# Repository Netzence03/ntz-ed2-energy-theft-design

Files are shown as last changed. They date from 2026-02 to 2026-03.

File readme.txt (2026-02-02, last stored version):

Notes:
 
1. All drill sizes are the maximum size provided by the manufacture (as required to calculate the minimum pad size).
2. All dimensions in building footprints are the maximum (including any tolerance) as defined by the manufacturer with the exception of row pitch (which is always nominal).  If only the normal sizing is provided we will input that dimension in mils, rounded to the nearest mil per our standards.
3. Slots are currently identified as entities describing the size of the slot (arcs, lines, etc.) on the board outline layer.  The extremities are identified with a via at each end.  These slots will either need to be:
	a. identified and dimensioned on your fabrication document
	b. or they will need to be converted to slots (assuming the targeted tool has a slot capability) using the process defined in your cad tool for identifying a padstack as a slot.  
		i. Typically this is only capable of a width and length of the slot and a size of the mill radius that creates the slot.  
		ii. Choosing to use the native tool slots will require removing entities on the board outline and the associated pads in the footprint.

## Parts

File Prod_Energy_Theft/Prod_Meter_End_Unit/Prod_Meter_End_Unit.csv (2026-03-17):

Reference | Qty | Value | DNP | Exclude from BOM | Exclude from Board | Footprint | Datasheet | Part Number
1k3,1k4 | 2 | R |  |  |  | Resistor_SMD:R_0805_2012Metric | ~ | RC0805FR-071KL
10k3,10k4 | 2 | R |  |  |  | Resistor_SMD:R_0805_2012Metric | ~ | RC0805FR-0710KL
C1,C2,C8,C13,C35,C40 | 6 | 100nf |  |  |  | Capacitor_SMD:C_0805_2012Metric | ~ | CL21B104KBCNNNC
C3 | 1 | 100uf |  |  |  | Capacitor_SMD:C_0805_2012Metric | ~ | EEE-FK1V101P
C5,C32 | 2 | 10uf |  |  |  | Capacitor_SMD:C_0805_2012Metric | ~ | CL21A106KOQNNNE
C6 | 1 | 150pf |  |  |  | Capacitor_SMD:C_0805_2012Metric | ~ | GRM1885C1H151JA01D
C9 | 1 | 47uf |  |  |  | Capacitor_SMD:C_0805_2012Metric | ~ | GRM32ER61E476KE15
C10,C12,C16,C18,C19 | 5 | 0.1u |  |  |  | Capacitor_SMD:C_0805_2012Metric | ~ | CL21B104KBCNNNC
C11,C17 | 2 | 10u |  |  |  | Capacitor_SMD:C_0805_2012Metric | ~ | CL21A106KOQNNNE
C14,C20 | 2 | 1u |  |  |  | Capacitor_SMD:C_0805_2012Metric | ~ | CL21B105KAFNNNE
C15 | 1 | 4.7u |  |  |  | Capacitor_SMD:C_0805_2012Metric | ~ | CL21A475KOQNNNE
C26,C27,C28,C29,C30,C31,C42,C43,C44,C45,C46,C47 | 12 | 22nf |  |  |  | Capacitor_SMD:C_0805_2012Metric | ~ | CL21B223KBCNNNC
C33,C34,C39 | 3 | 4.7uf |  |  |  | Capacitor_SMD:C_0805_2012Metric | ~ | CL21A475KOQNNNE
C36,C37 | 2 | 220nf |  |  |  | Capacitor_SMD:C_0805_2012Metric | ~ | CL21B224KBCNNNC
C38,C41 | 2 | 20pf |  |  |  | Capacitor_SMD:C_0805_2012Metric | ~ | GRM1885C1H200JA01D
D5,D6,D9,D10 | 4 | SS34 |  |  |  | Diode_SMD:D_SMA | https://www.vishay.com/docs/88751/ss32.pdf | SS34
D7 | 1 | Green |  |  |  | theftdetection:LEDC2012X120N | https://mm.digikey.com/Volume0/opasdata/d220001/medias/docus/895/LTST-C170GKT.pdf | LTST-C170GKT
D8 | 1 | Red |  |  |  | theftdetection:LEDC2012X120N | https://componentsearchengine.com/Datasheets/1/LTST-C170KRKT.pdf | LTST-C170GKT
D11,D12 | 2 | D |  |  |  | Diode_SMD:D_SOD-123 | ~ | B5819W
F1 | 1 | 0ZCH0110AF2E |  |  |  | Footprints.kicad_mod:FUSC3226X100N | https://www.belfuse.com/resources/datasheets/circuitprotection/ds-cp-0zch-series.pdf | 0ZCH0110AF2E
F3 | 1 | Polyfuse |  |  |  | Fuse:Fuse_1206_3216Metric | ~ | MF-R110
IC1 | 1 | MP1584EN-LF-Z |  |  |  | theftdetection:SOIC127P600X170-9N |  | MP1584EN-LF-Z
J1,J2,J3,J4,J10,J11,J12,J13 | 8 | Screw_Terminal_01x02 |  |  |  | TerminalBlock_Phoenix:TerminalBlock_Phoenix_MKDS-1,5-2-5.08_1x02_P5.08mm_Horizontal | ~ | MKDS-1,5-2-5.08
J6 | 1 | Jack-DC |  |  |  | Connector_BarrelJack:BarrelJack_GCT_DCJ200-10-A_Horizontal | ~ | PJ-102A
J7 | 1 | SS-52400-002 |  |  |  | theftdetection:BELFUSE_SS-52400-002 |  | SS-52400-002
J8 | 1 | U.FL-R-SMT_01_ |  |  |  | theftdetection:HRS_U.FL-R-SMT_01_ |  | U.FL-R-SMT-1
K1 | 1 | HFD2/012-S-L2-D |  |  |  | theftdetection:RELAY10_HFD2&slash_012_HNG | HFD2/012-S-L2-D | HFD2/012-S-L2-D
L1 | 1 | 15uH |  |  |  | Inductor_SMD:L_0805_2012Metric | ~ | SRN6045TA-150M
Q1,Q2 | 2 | BC817 |  |  |  | Package_TO_SOT_SMD:SOT-23 | https://www.onsemi.com/pub/Collateral/BC818-D.pdf | BC817
Q5,Q6 | 2 | AO3400A |  |  |  | Package_TO_SOT_SMD:SOT-23 | http://www.aosmd.com/pdfs/datasheet/AO3400A.pdf | AO3400A
R1,R15,R16 | 3 | 100k |  |  |  | Resistor_SMD:R_0805_2012Metric | ~ | RC0805FR-07100KL
R2 | 1 | 24k9 |  |  |  | Resistor_SMD:R_0805_2012Metric | ~ | RC0805FR-0724K9L
R9,R12 | 2 | 4K7 |  |  |  | Resistor_SMD:R_0805_2012Metric | ~ | RC0805FR-074K7L
R10,R11,R23,R24,R25,R26,R42,R43,R45,R46,R48,R49 | 12 | 1K |  |  |  | Resistor_SMD:R_0805_2012Metric | ~ | RC0805FR-071KL
R13,R14 | 2 | 5K1 |  |  |  | Resistor_SMD:R_0805_2012Metric | ~ | RC0805FR-0751KL
R17 | 1 | 210k |  |  |  | Resistor_SMD:R_0805_2012Metric | ~ | RC0805FR-07210KL
R20,R21,R22,R41,R44,R47 | 6 | 10 |  |  |  | Resistor_SMD:R_0805_2012Metric | ~ | RC0805FR-0710RL
R27,R28,R38,R39,R40 | 5 | 10k |  |  |  | Resistor_SMD:R_0805_2012Metric | ~ | RC0805FR-0710KL
R29 | 1 | 40k2 |  |  |  | Resistor_SMD:R_0805_2012Metric | ~ | RC0805FR-0740KL
R30 | 1 | 20k |  |  |  | Resistor_SMD:R_0805_2012Metric | ~ | RC0805FR-0720KL
R31,R32,R33 | 3 | 10K |  |  |  | Resistor_SMD:R_0805_2012Metric | ~ | RC0805FR-0710KL
R34 | 1 | 39k |  |  |  | Resistor_SMD:R_0805_2012Metric | ~ | RC0805FR-0739KL
R35 | 1 | IK |  |  |  | Resistor_SMD:R_0805_2012Metric | ~ | RC0805FR-071KL
R36,R37 | 2 | 330 |  |  |  | Resistor_SMD:R_0805_2012Metric | ~ | RC0805FR-07330RL
S1 | 1 | BOOT |  |  |  | theftdetection:SW_USLPT2819DT2TR |  | USLPT2819DT2TR
S2 | 1 | RESET |  |  |  | theftdetection:SW_USLPT2819DT2TR |  | USLPT2819DT2TR
U1 | 1 | TPS7A2033PDBVR |  |  |  | theftdetection:SOT95P280X145-5N |  | TPS7A2033PDBVR
U2 | 1 | ESP32-C6-MINI-1 |  |  |  | RF_Module:ESP32-C6-MINI-1 | https://www.espressif.com/sites/default/files/documentation/esp32-c6-mini-1_mini-1u_datasheet_en.pdf | ESP32-C6-MINI-1
U4 | 1 | CP2102N-Axx-xQFN20 |  |  |  | theftdetection:IC_CP2102N-A01-GQFN20 | https://www.silabs.com/documents/public/data-sheets/cp2102n-datasheet.pdf | CP2102N-A02-GQFN20
U5 | 1 | ADE7816ACPZ |  |  |  | adefootprint:QFN50P600X600X80-41N |  | ADE7816ACPZ
U6 | 1 | USBLC6-2SC6 |  |  |  | Package_TO_SOT_SMD:SOT-23-6 | https://www.st.com/resource/en/datasheet/usblc6-2.pdf | USBLC6-2SC6
U7 | 1 | AP2112K-3.3 |  |  |  | Package_TO_SOT_SMD:SOT-23-5 | https://www.diodes.com/assets/Datasheets/AP2112.pdf | AP2112K-3.3
U8 | 1 | E32-433T20S |  |  |  | theftdetection:MODULE_E32-433T20S |  | E32-433T20S
Y2 | 1 | Crystal |  |  |  | Crystal:Crystal_SMD_3225-4Pin_3.2x2.5mm | ~ | TSX-3225

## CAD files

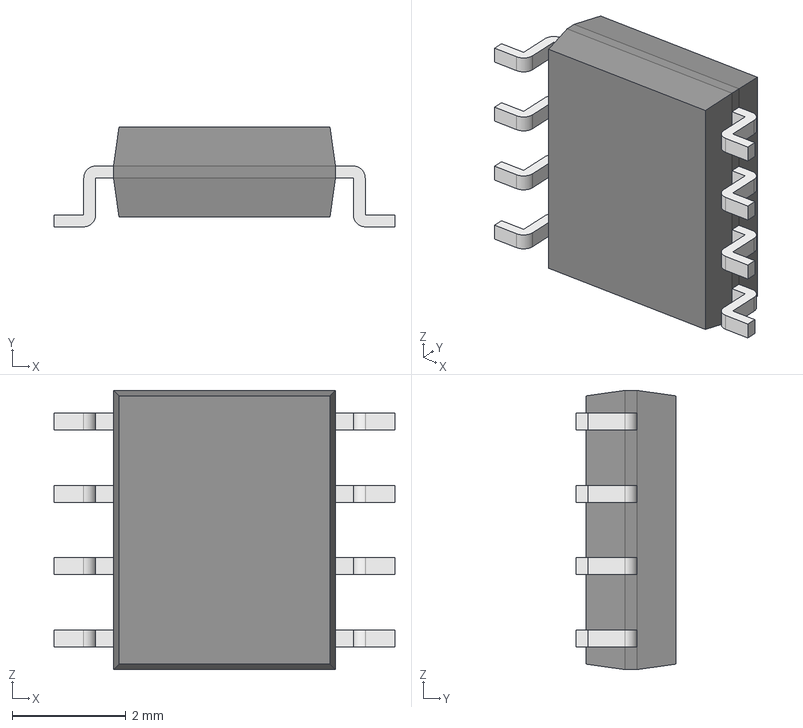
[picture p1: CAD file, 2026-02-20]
Prod_Energy_Theft/Prod_Pole_End_Unit/TPS54331DG4/TPS54331DG4.step
5.99 x 1.75 x 4.91 mm
Body001 (Mirror #1) x 4
XY-plane x 12
X-axis x 12

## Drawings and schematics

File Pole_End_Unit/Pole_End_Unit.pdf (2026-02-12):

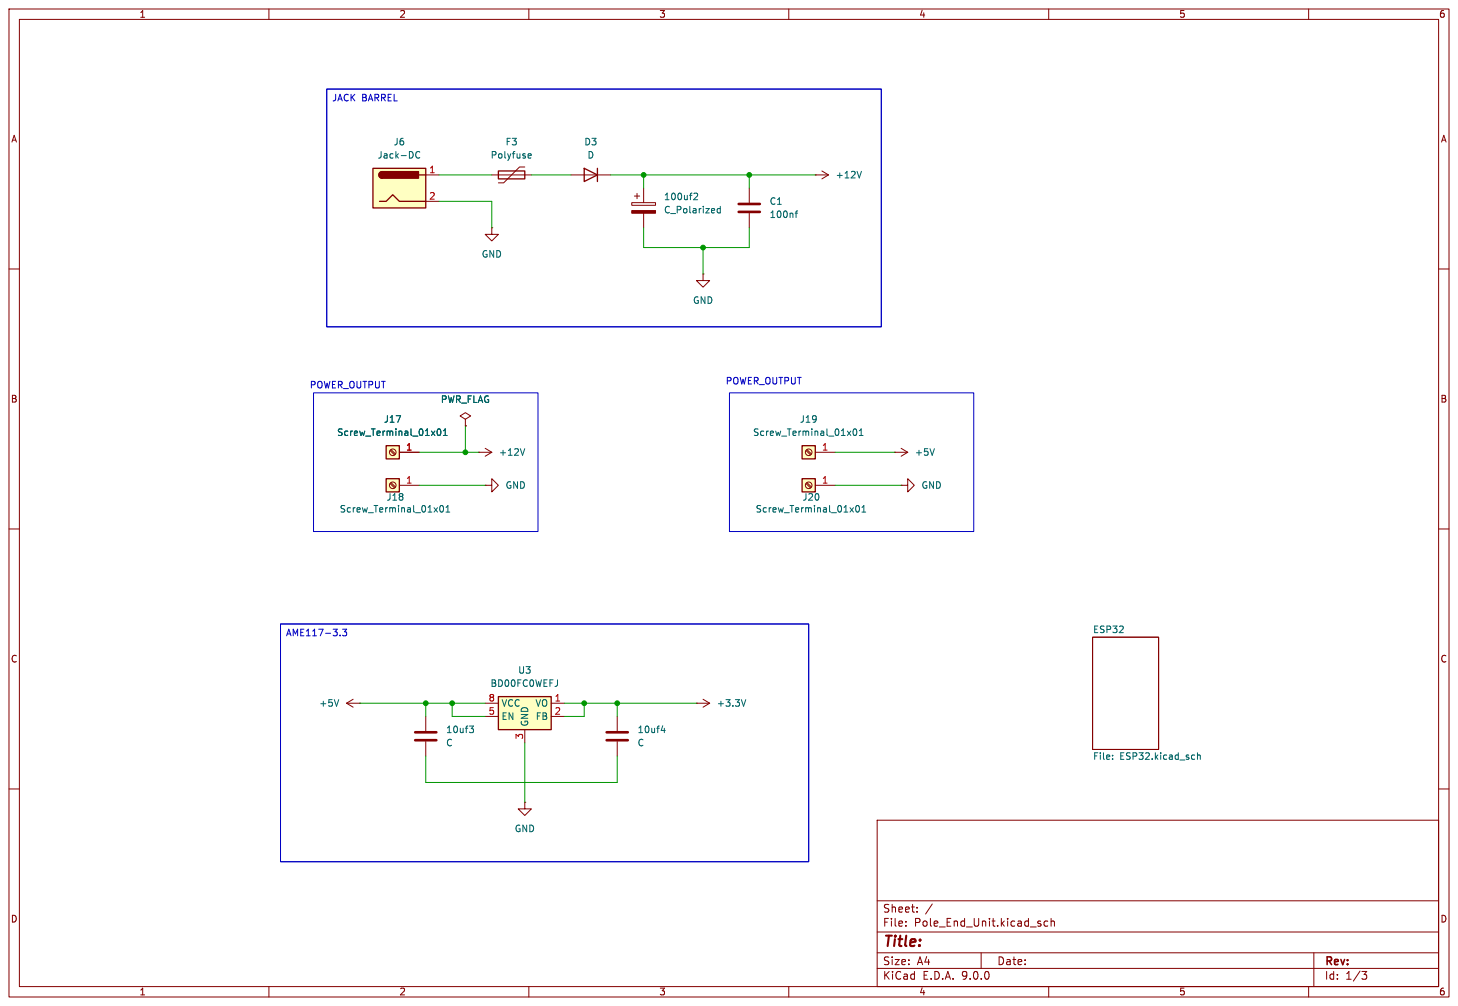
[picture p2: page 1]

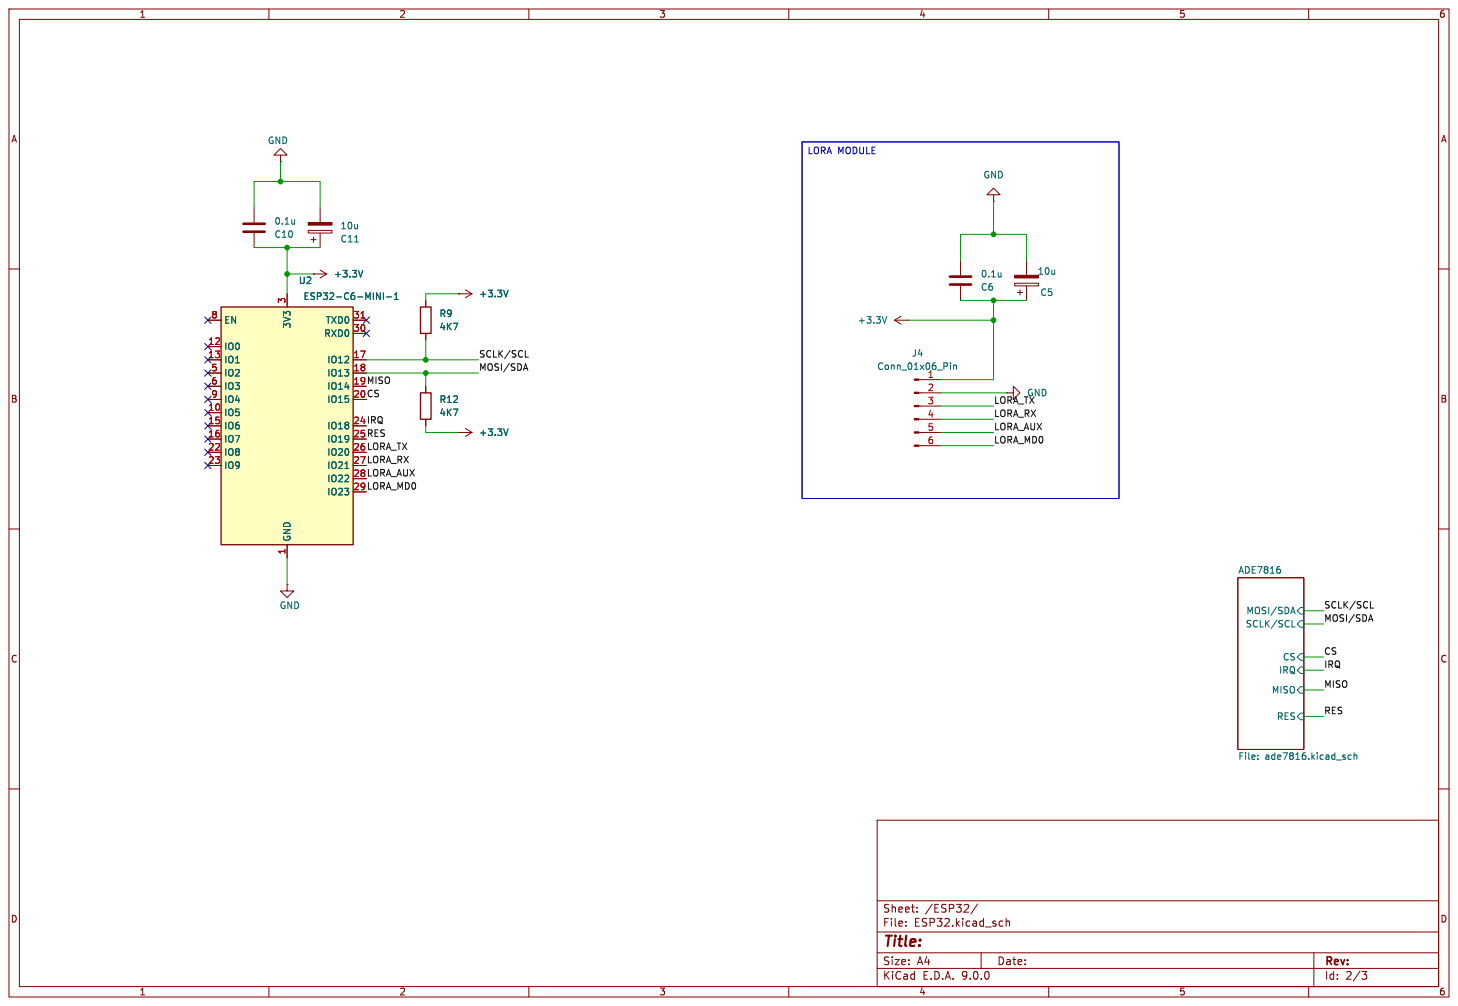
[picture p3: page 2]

LORA MODULE U2ESP32-C6-MINI-1 EN 8

SCLK/SCL MOSI/SDA

SCLK/SCL ADE7816 File: ade7816.kicad_sch GND

Id: 2/3 Title: File: ESP32.kicad_sch Sheet: /ESP32/

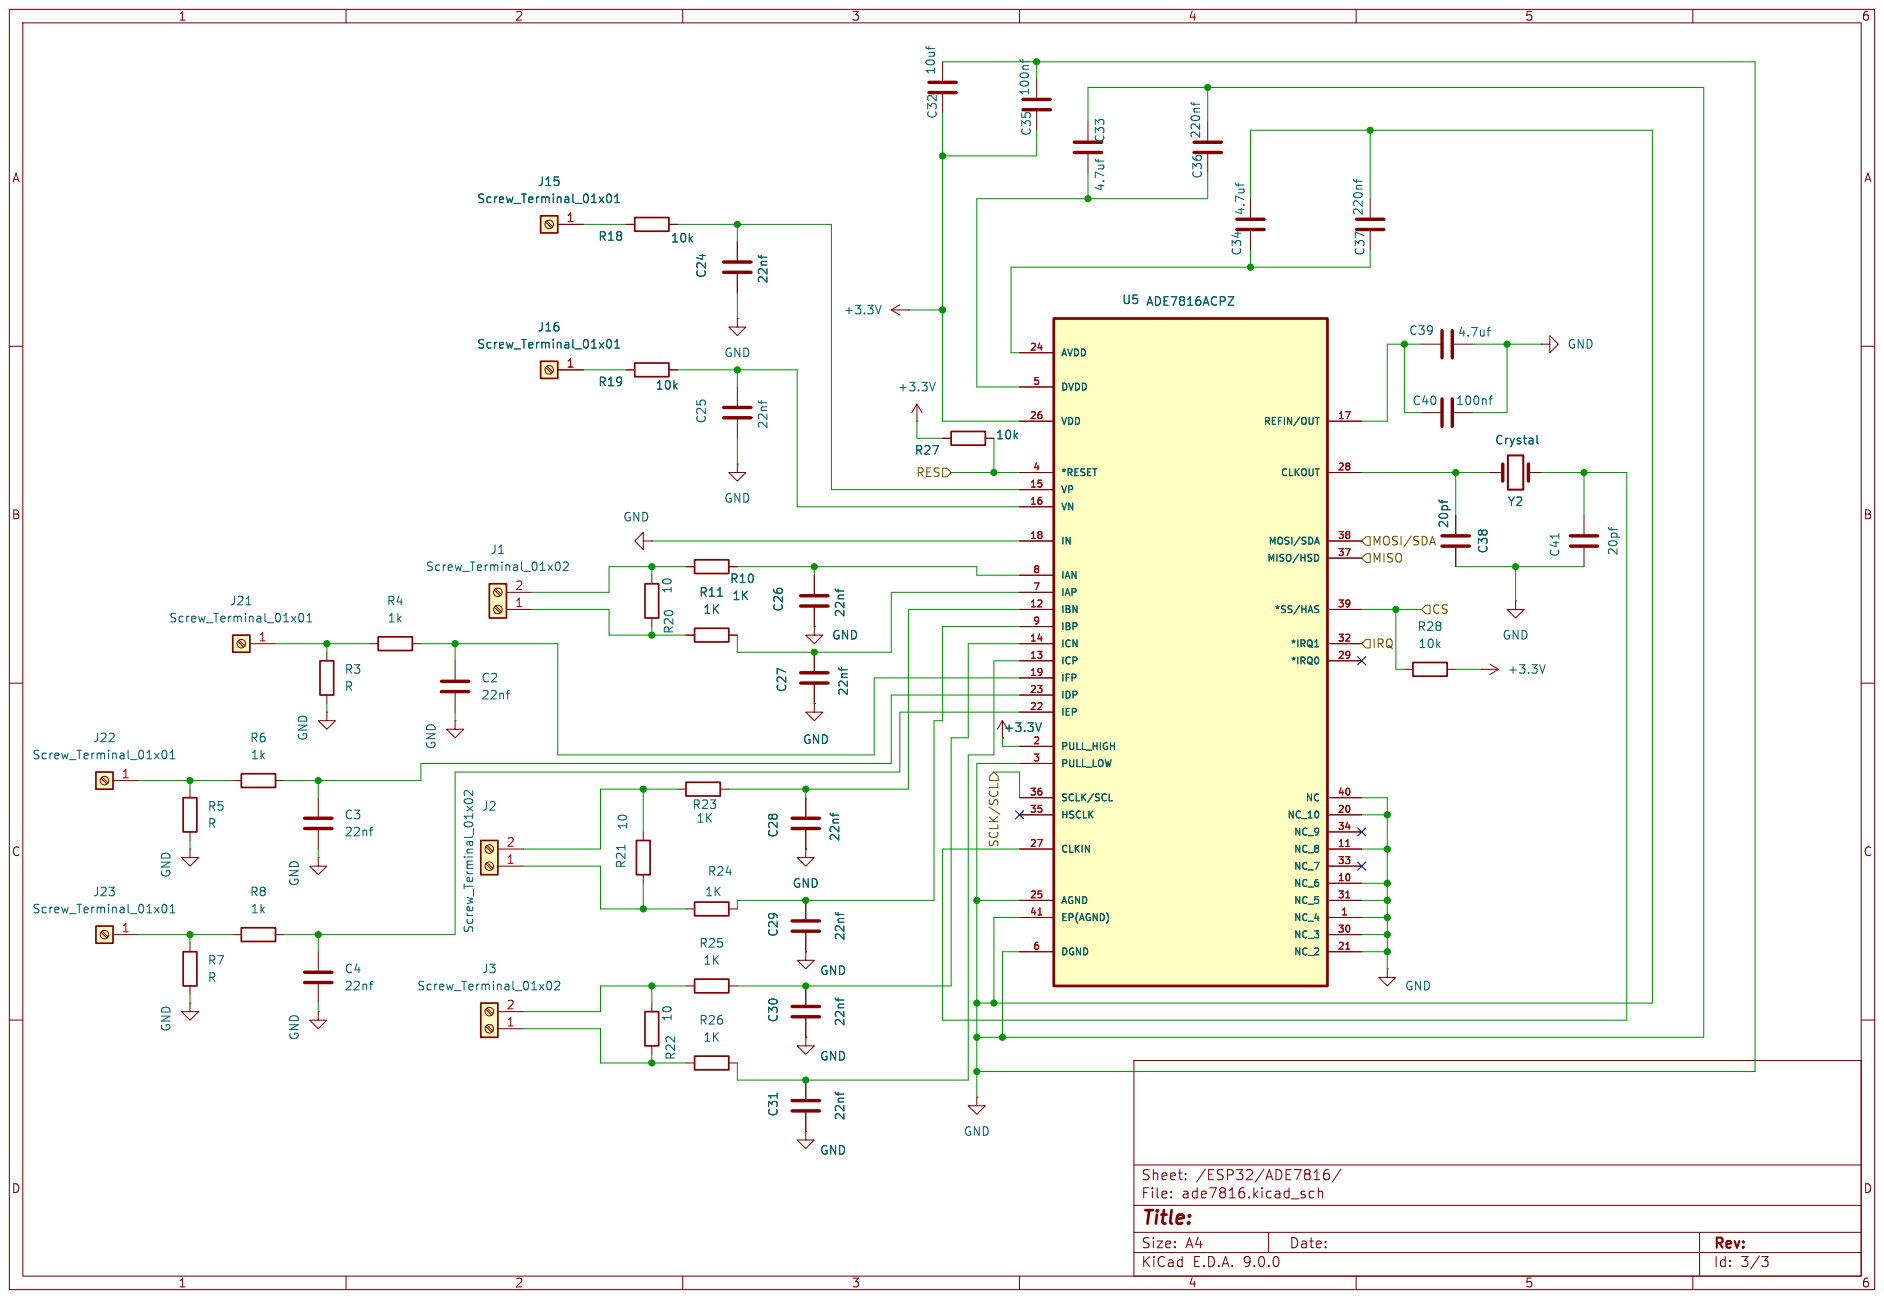
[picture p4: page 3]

Id: 3/3 Title: File: ade7816.kicad_sch Sheet: /ESP32/ADE7816/

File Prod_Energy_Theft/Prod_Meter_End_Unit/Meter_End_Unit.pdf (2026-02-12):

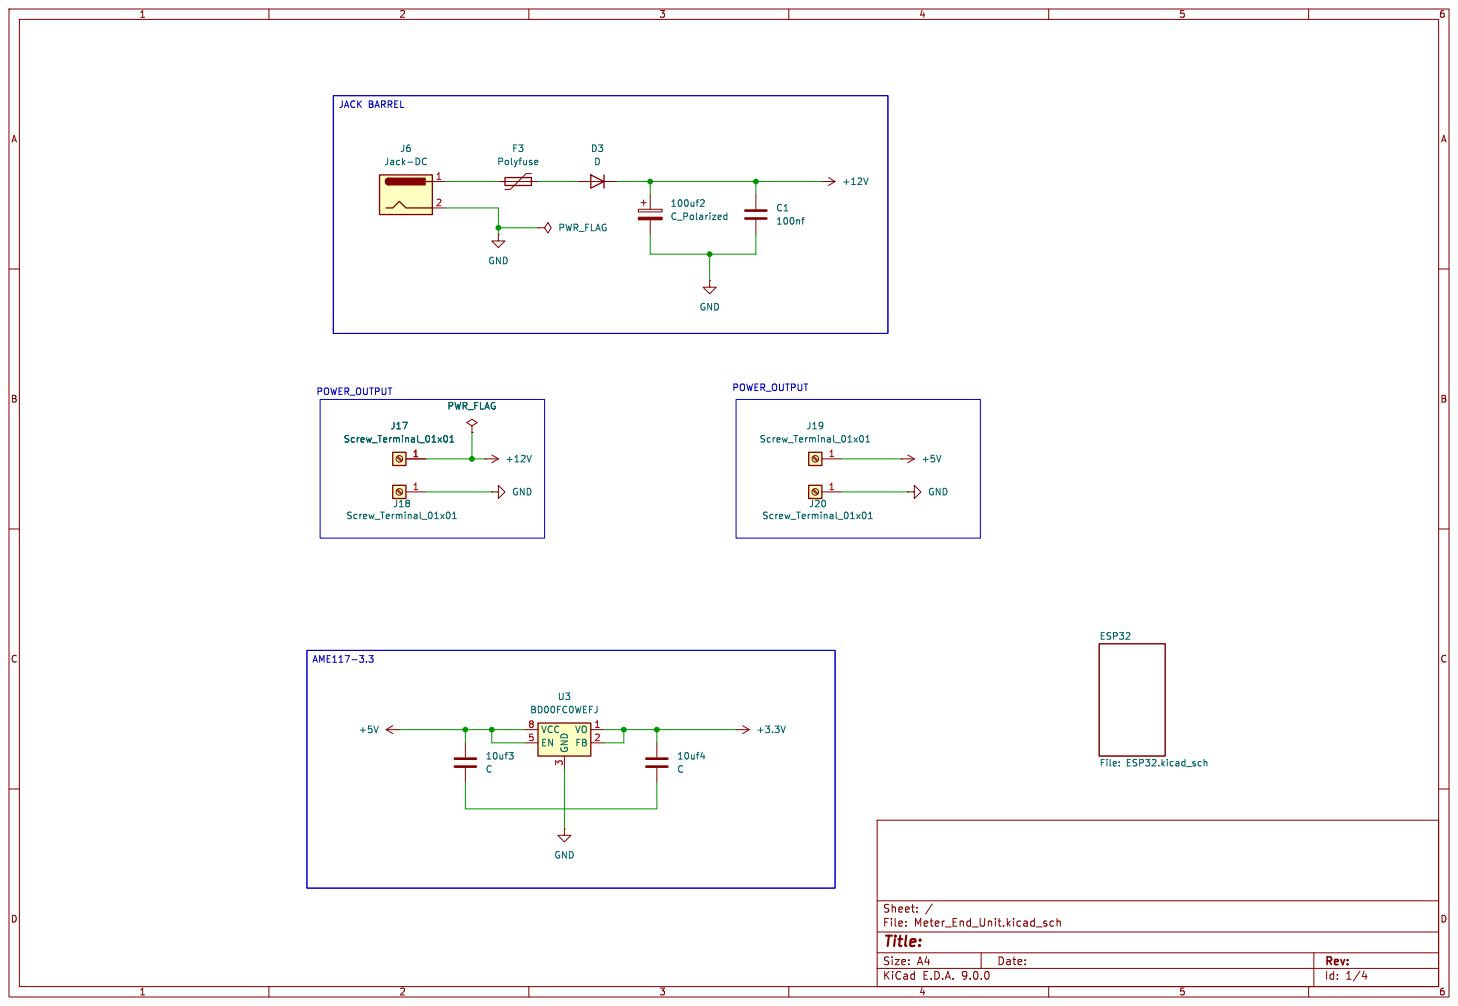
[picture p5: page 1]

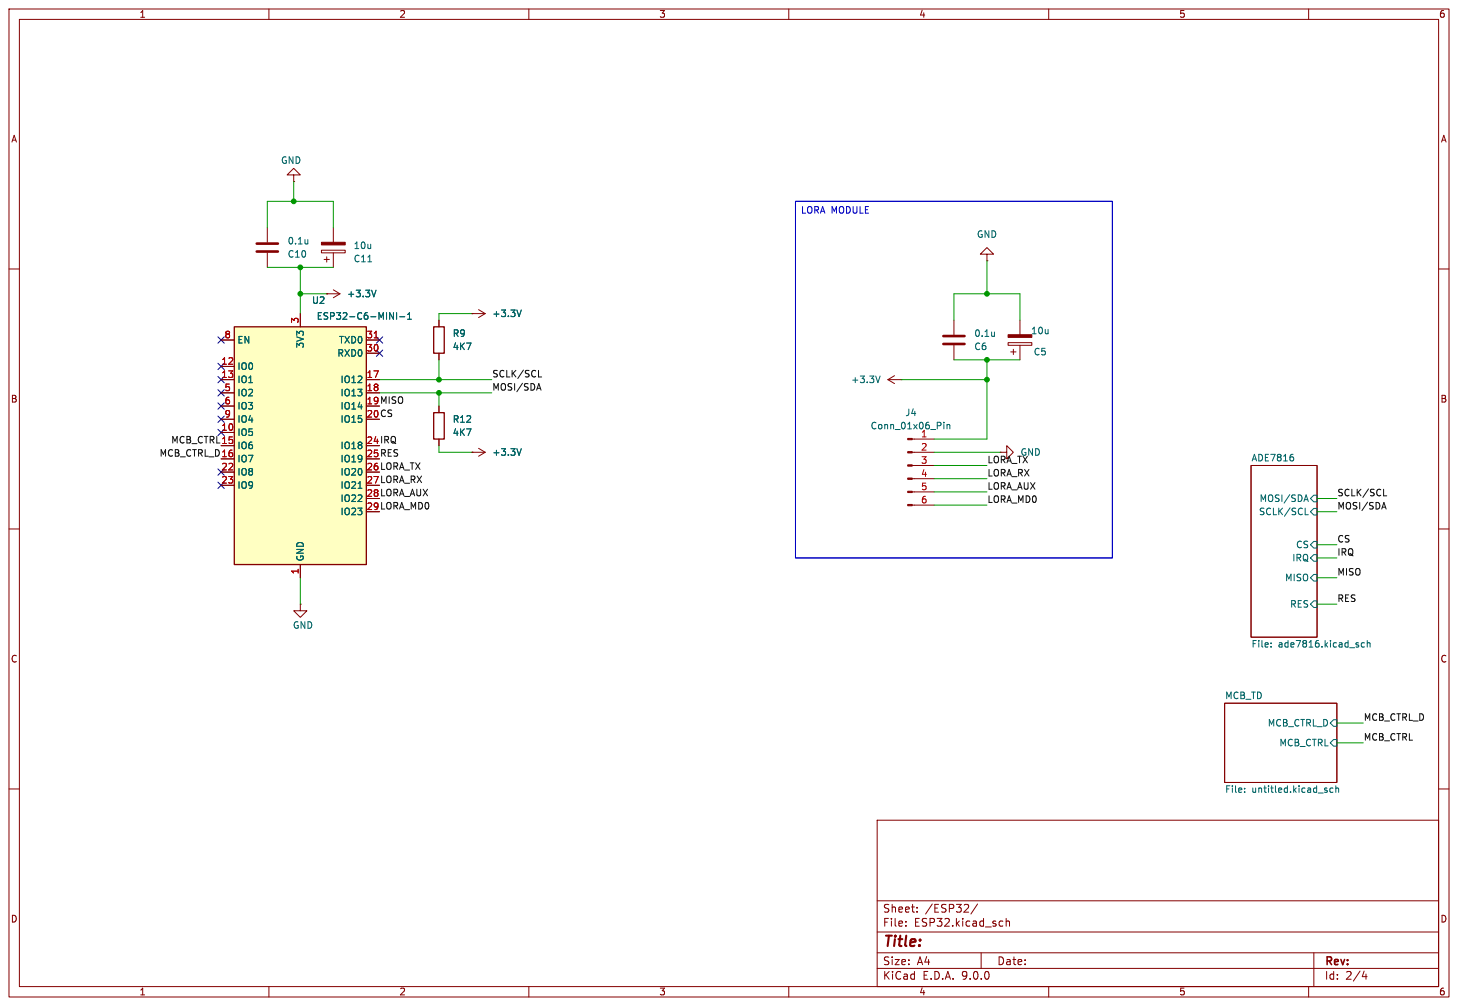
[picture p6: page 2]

CSMOSI/SDA MCB_CTRL SCLK/SCL
SCLK/SCL MOSI/SDA

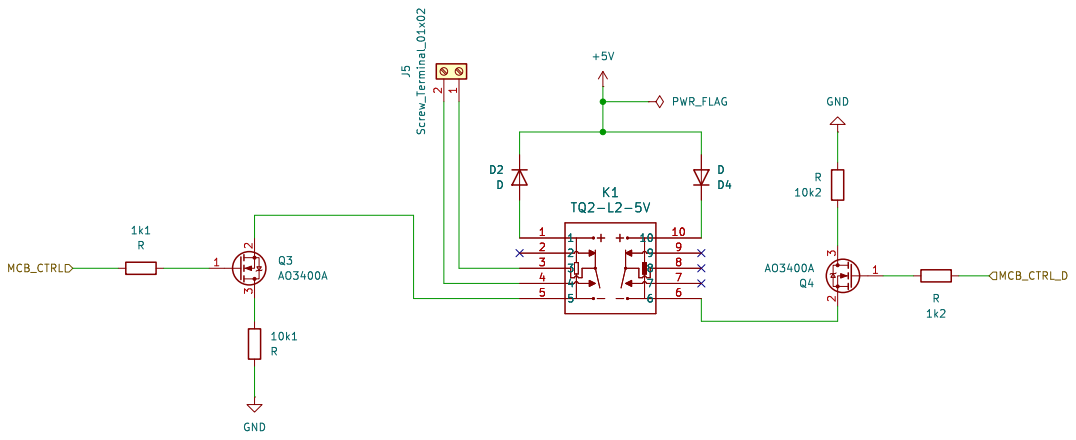
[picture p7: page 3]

Id: 3/4 Title: File: untitled.kicad_sch Sheet: /ESP32/MCB_TD/

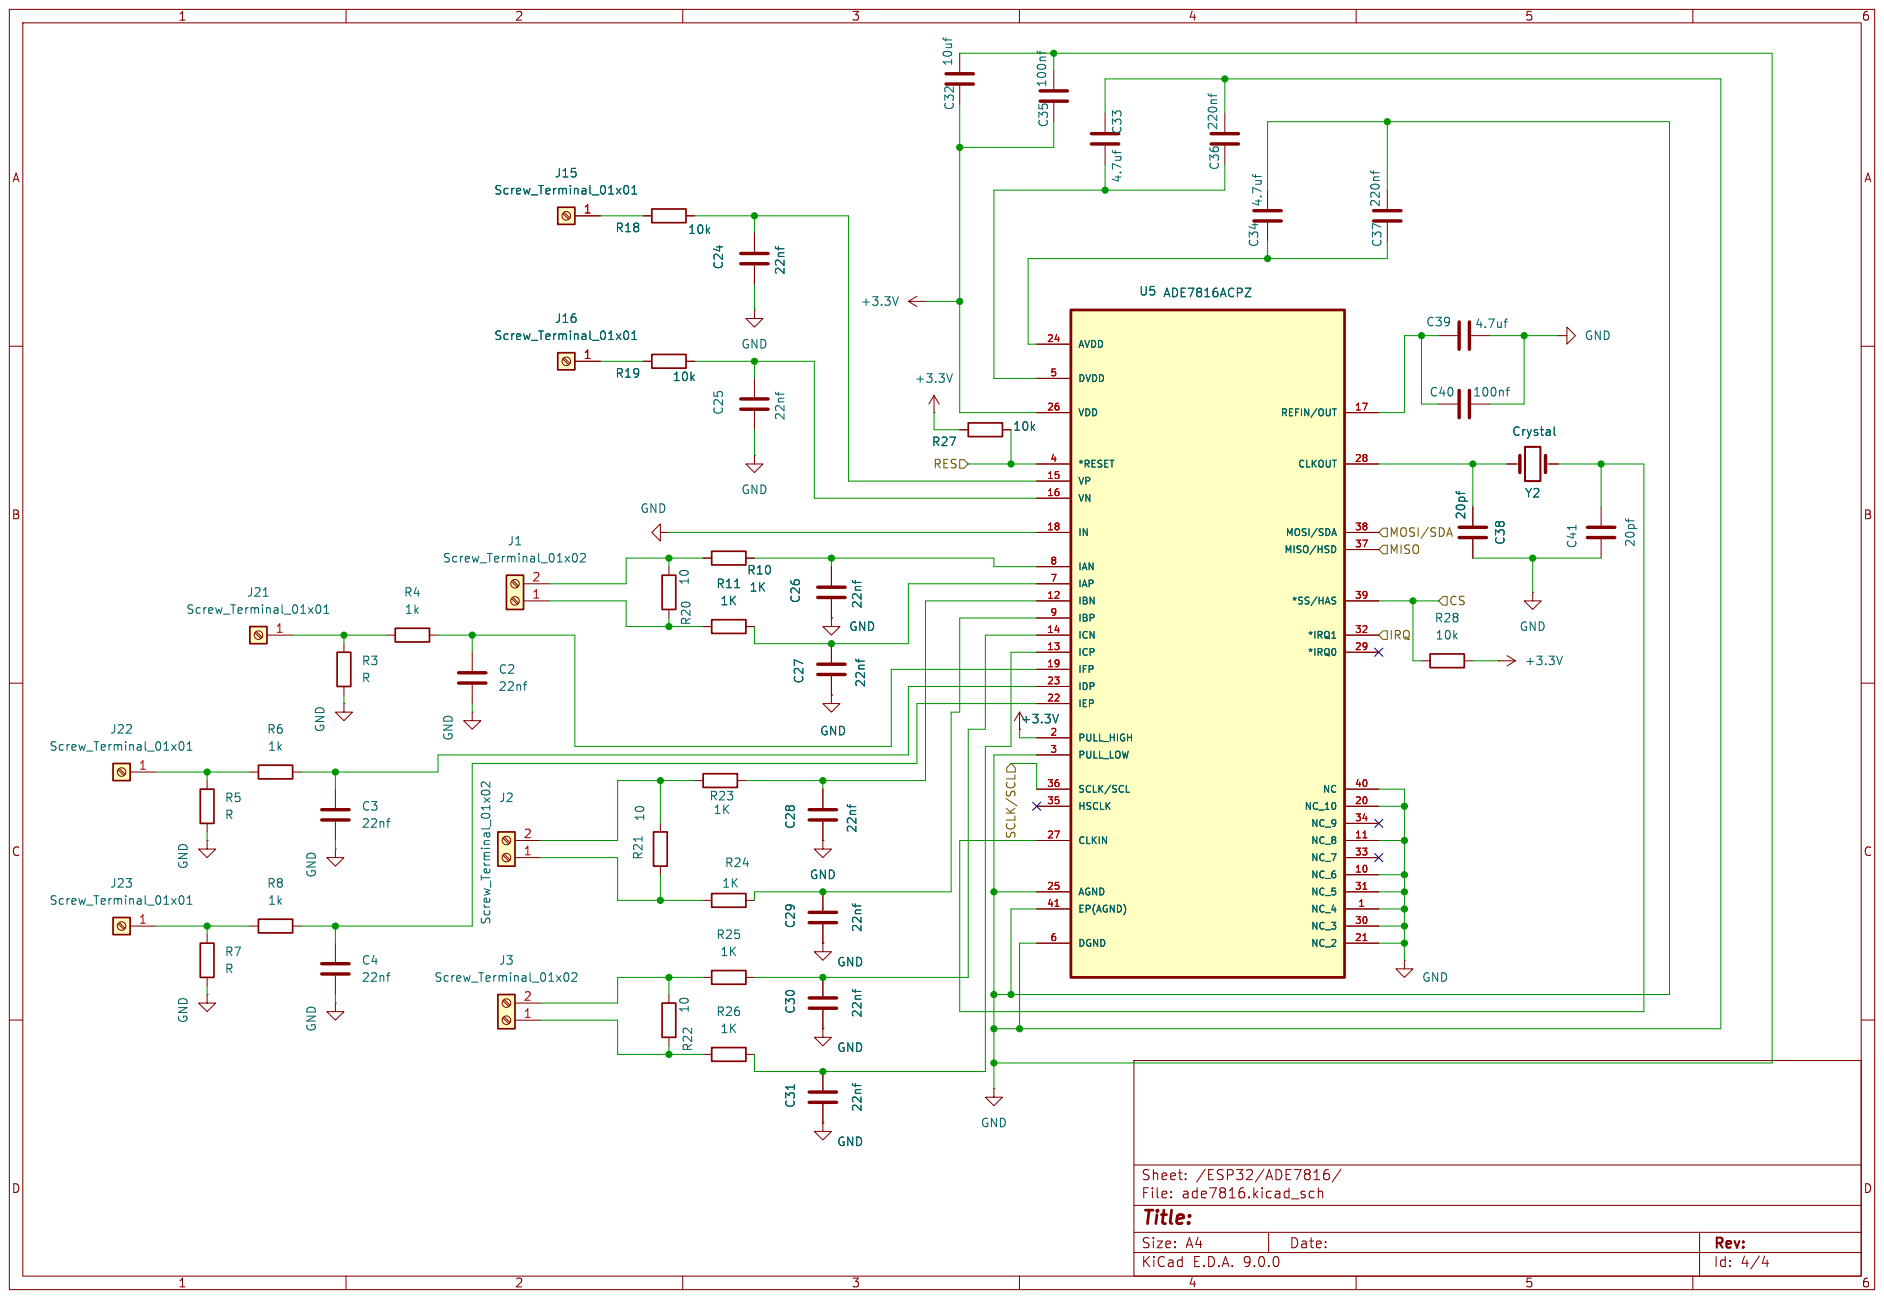
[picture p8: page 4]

Id: 4/4 Title: File: ade7816.kicad_sch Sheet: /ESP32/ADE7816/ 1
J21 Screw_Terminal_01x01 GND

CS MISO MOSI/SDA

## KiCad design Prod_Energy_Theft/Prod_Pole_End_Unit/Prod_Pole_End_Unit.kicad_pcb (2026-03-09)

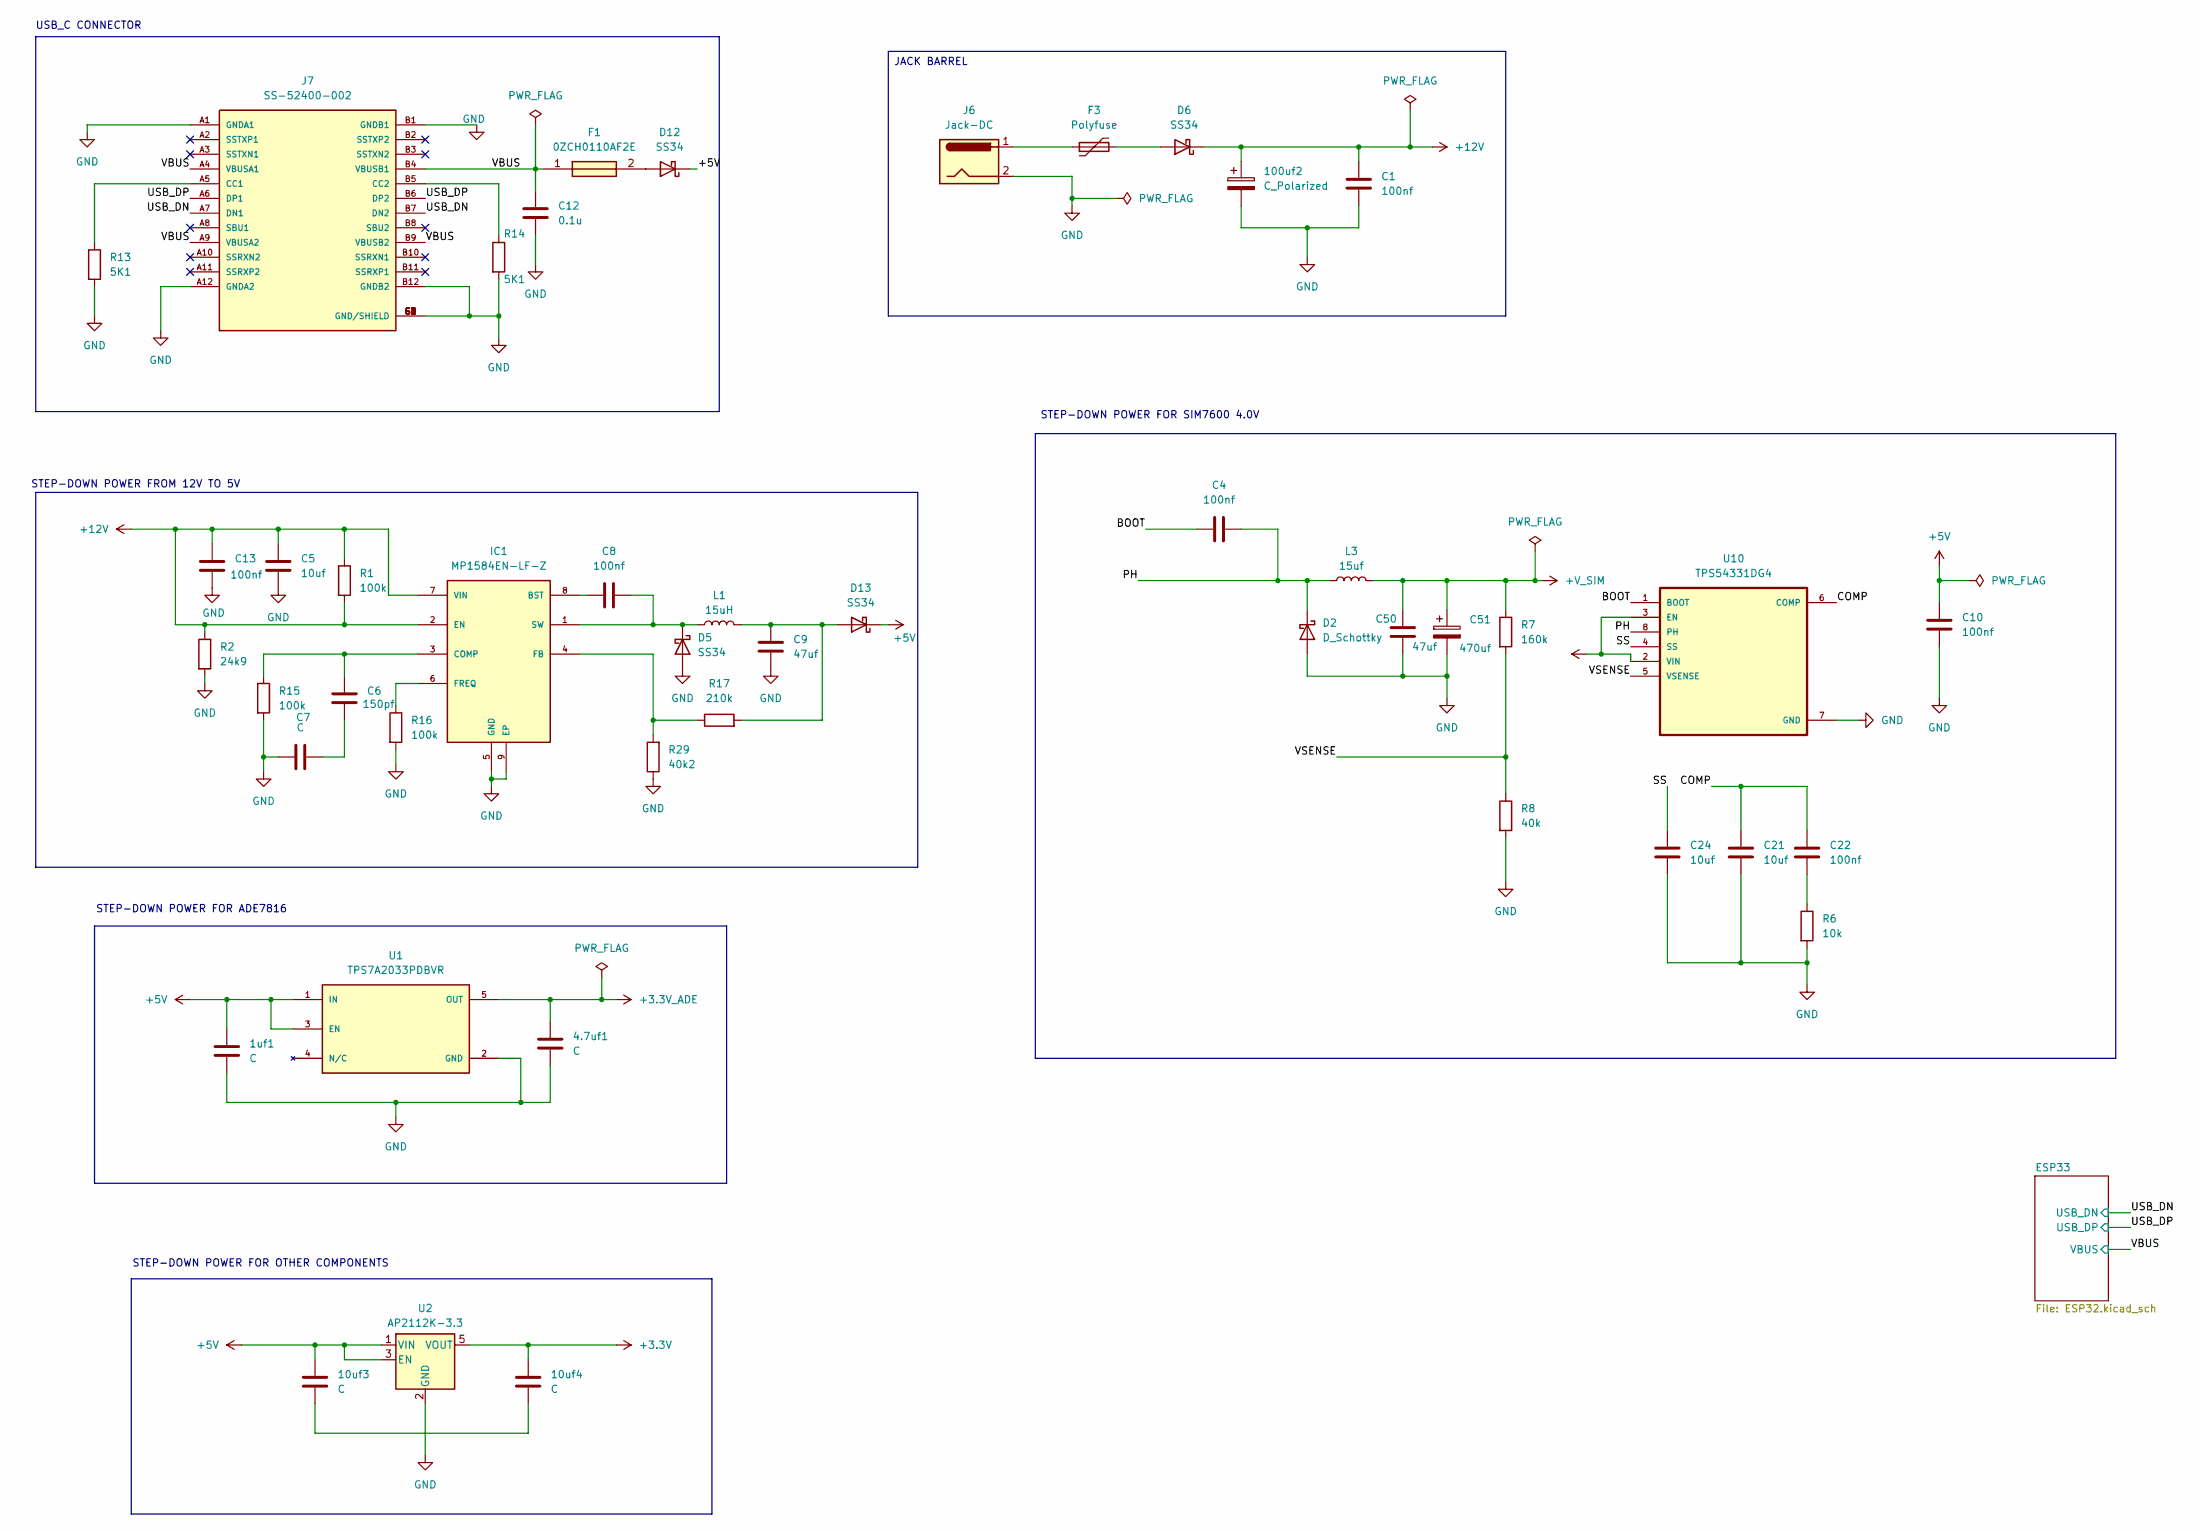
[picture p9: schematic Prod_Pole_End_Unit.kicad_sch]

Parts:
1uf1, 4.7uf1, 10uf3, 10uf4: C; C_0805_2012Metric
100uf2: C_Polarized; C_0805_2012Metric
C1, C4, C8, C10, C13, C22: 100nf; C_0805_2012Metric
C5, C21, C24: 10uf; C_0805_2012Metric
C6: 150pf; C_0805_2012Metric
C7: C; C_0805_2012Metric
C9: 47uf; C_0805_2012Metric; Voltage 16V; MPN GRM32ER71C476KE15
C12: 0.1u; C_0805_2012Metric
C50: 47uf; C_0805_2012Metric
C51: 470uf; C_0805_2012Metric
D2: D_Schottky; D_SMA
D5, D6, D12, D13: SS34; D_SMA
F1: 0ZCH0110AF2E; FUSC3226X100N; Manufacturer_Part_Number 0ZCH0110AF2E
F3: Polyfuse; Fuse_1206_3216Metric
IC1: MP1584EN-LF-Z; SOIC127P600X170-9N; MOUSER_PART_NUMBER 946-MP1584ENLFZ
J6: Jack-DC; BarrelJack_GCT_DCJ200-10-A_Horizontal
J7: SS-52400-002; BELFUSE_SS-52400-002; PARTREV A0
L1: 15uH; L_0805_2012Metric
L3: 15uf; L_0805_2012Metric
R1, R15, R16: 100k; R_0805_2012Metric
R2: 24k9; R_0805_2012Metric
R6: 10k; R_0805_2012Metric
R7: 160k; R_0805_2012Metric
R8: 40k; R_0805_2012Metric
R13, R14: 5K1; R_0805_2012Metric
R17: 210k; R_0805_2012Metric
R29: 40k2; R_0805_2012Metric
U1: TPS7A2033PDBVR; SOT95P280X145-5N; PARTREV H
U2: AP2112K-3.3; SOT-23-5
U10: TPS54331DG4; SOIC127P599X175-8N

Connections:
+3.3V: 10uf4.1, U2.5 (VOUT); also elsewhere on the board
+3.3V_ADE: 4.7uf1.1, U1.5 (OUT); also elsewhere on the board
+5V: 1uf1.1, 10uf3.1, C10.1, D12.1 (K), D13.1 (K), U1.1 (IN), U1.3 (EN), U2.1 (VIN), U2.3 (EN), U10.2 (VIN), U10.3 (EN)
+12V: 100uf2.1, C1.1, C5.1, C13.1, D6.1 (K), IC1.2 (EN), IC1.7 (VIN), R1.1, R1.2, R2.1
+V_SIM: C50.1, C51.1, L3.2, R7.1; also elsewhere on the board
/BOOT: C4.1, U10.1 (BOOT)
/COMP: C21.1, C22.1, U10.6 (COMP)
/PH: C4.2, D2.1 (K), L3.1, U10.8 (PH)
/SS: C24.1, U10.4 (SS)
/USB_DN: J7.A7 (DN1), J7.B7 (DN2); also elsewhere on the board
/USB_DP: J7.A6 (DP1), J7.B6 (DP2); also elsewhere on the board
/VBUS: C12.1, F1.1, J7.A4 (VBUSA1), J7.A9 (VBUSA2), J7.B4 (VBUSB1), J7.B9 (VBUSB2); also elsewhere on the board
/VSENSE: R7.2, R8.1, U10.5 (VSENSE)
GND: 1uf1.2, 4.7uf1.2, 100uf2.2, C1.2, C5.2, C7.1, C9.2, C10.2, C12.2, C13.2, C21.2, C24.2, C50.2, C51.2, D2.2 (A), D5.2 (A), IC1.5 (GND), IC1.9 (EP), J6.2, J7.A1 (GNDA1), J7.A12 (GNDA2), J7.B1 (GNDB1), J7.B12 (GNDB2), J7.G1 (GND/SHIELD), J7.G2 (GND/SHIELD), J7.G3 (GND/SHIELD), J7.G4 (GND/SHIELD), J7.S1 (GND/SHIELD), J7.S2 (GND/SHIELD), J7.S3 (GND/SHIELD), J7.S4 (GND/SHIELD), R2.2, R6.2, R8.2, R13.2, R14.2, R15.2, R16.2, R29.1, U1.2 (GND), U2.2 (GND), U10.7 (GND); also elsewhere on the board
unnamed: 10uf3.2, 10uf4.2
unnamed: C6.2, C7.2
unnamed: C22.2, R6.1
unnamed: C8.2, D5.1 (K), IC1.1 (SW), L1.1
unnamed: D6.2 (A), F3.2
unnamed: D12.2 (A), F1.2
unnamed: C9.1, D13.2 (A), L1.2, R17.2
unnamed: F3.1, J6.1
unnamed: C8.1, IC1.8 (BST)
unnamed: C6.1, IC1.3 (COMP), R15.1
unnamed: IC1.4 (FB), R17.1, R29.2
unnamed: IC1.6 (FREQ), R16.1
unnamed: J7.A5 (CC1), R13.1
unnamed: J7.B5 (CC2), R14.1

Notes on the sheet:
STEP-DOWN POWER FROM 12V TO 5V
STEP-DOWN POWER FOR ADE7816
STEP-DOWN POWER FOR SIM7600 4.0V
STEP-DOWN POWER FOR OTHER COMPONENTS
USB_C CONNECTOR
JACK BARREL

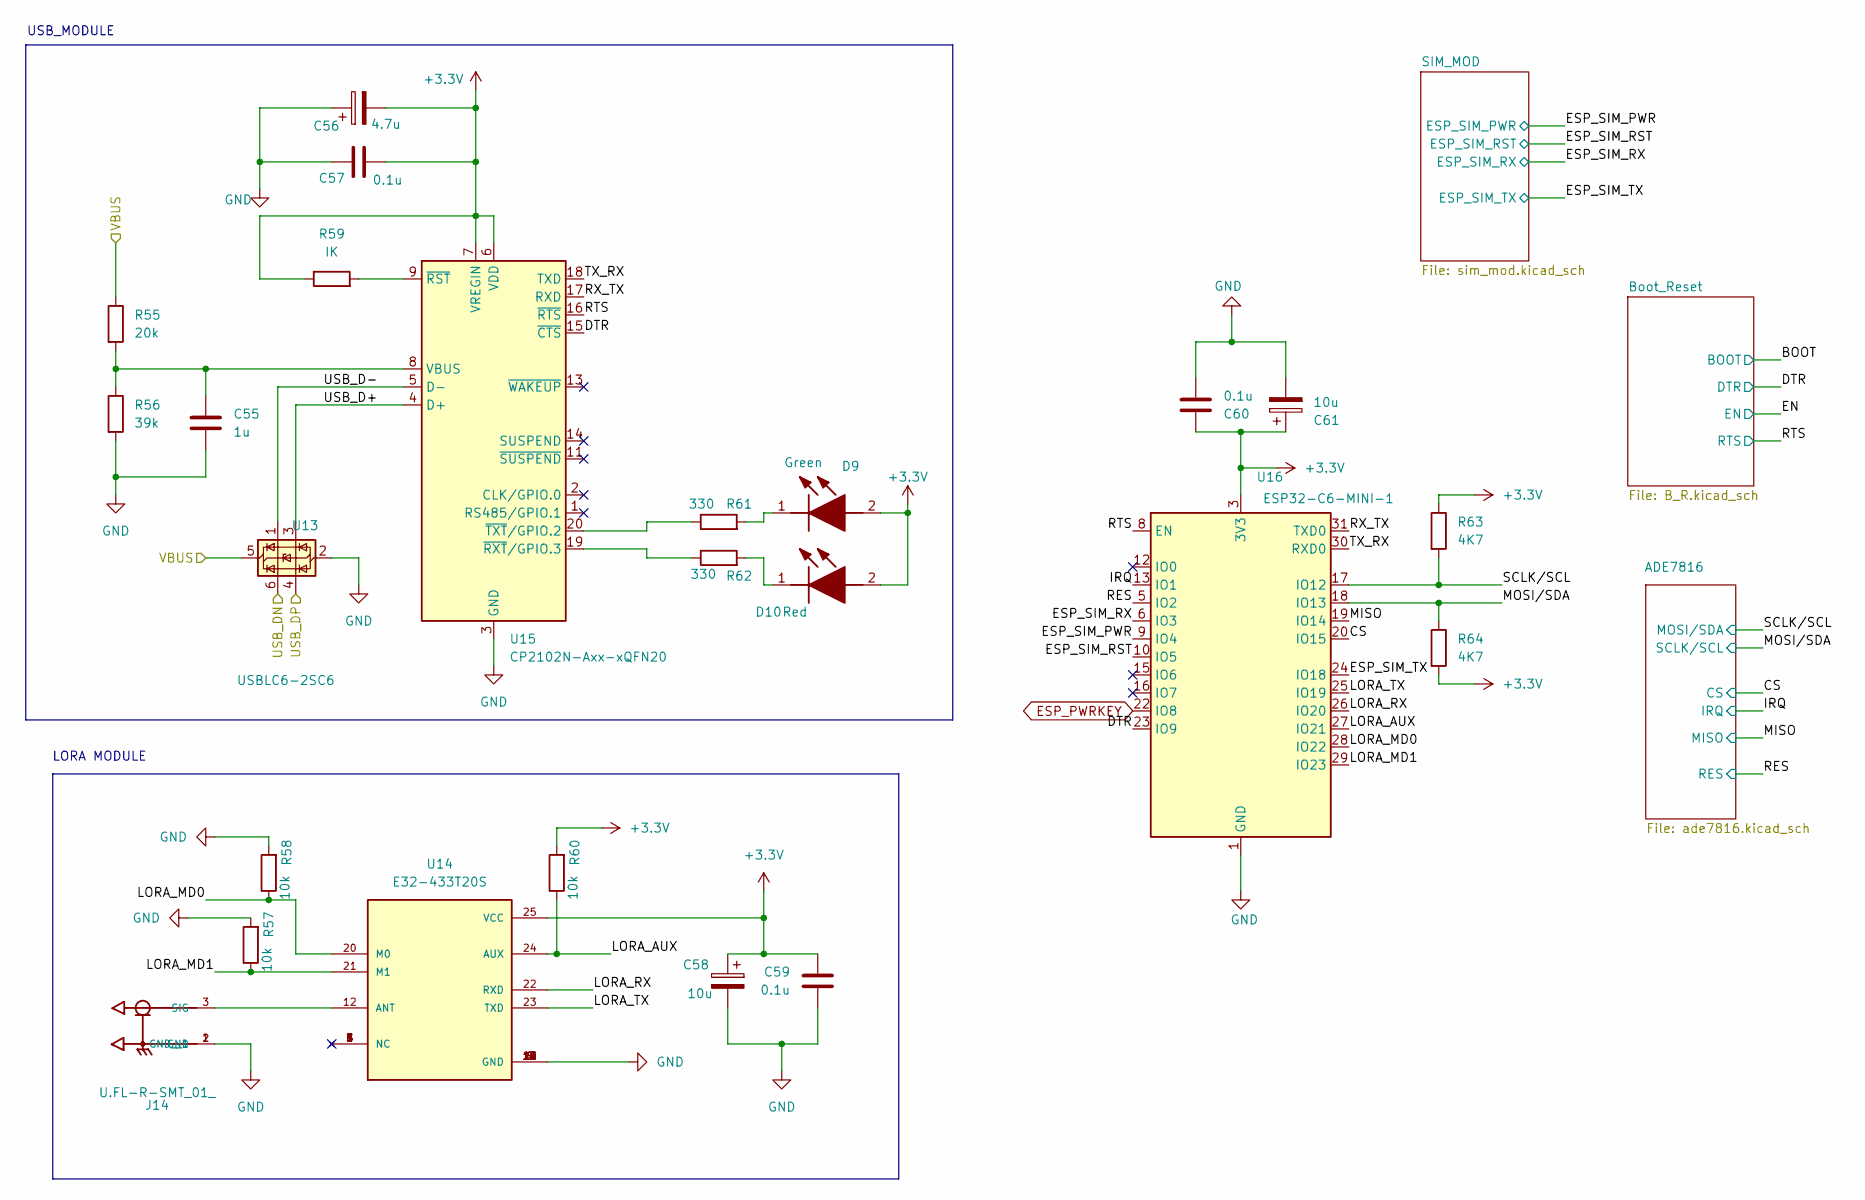
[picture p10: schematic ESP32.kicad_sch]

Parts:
C55: 1u; C_0805_2012Metric
C56: 4.7u; C_0805_2012Metric
C57, C59, C60: 0.1u; C_0805_2012Metric
C58, C61: 10u; C_0805_2012Metric
D9: Green; LEDC2012X120N; Manufacturer_Part_Number LTST-C170GKT; Mouser Part Number 859-LTST-C170GKT
D10: Red; LEDC2012X120N; Manufacturer_Part_Number LTST-C170KRKT; Mouser Part Number 859-LTST-C170KRKT
J14: U.FL-R-SMT_01_; HRS_U.FL-R-SMT_01_
R55: 20k; R_0805_2012Metric
R56: 39k; R_0805_2012Metric
R57, R58, R60: 10k; R_0805_2012Metric
R59: IK; R_0805_2012Metric
R61, R62: 330; R_0805_2012Metric
R63, R64: 4K7; R_0805_2012Metric
U13: USBLC6-2SC6; SOT-23-6
U14: E32-433T20S; MODULE_E32-433T20S; PARTREV 1.00
U15: CP2102N-Axx-xQFN20; IC_CP2102N-A01-GQFN20
U16: ESP32-C6-MINI-1

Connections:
+3.3V: C56.2, C57.2, C58.1, C59.1, C60.1, C61.1, D9.2 (A), D10.2 (A), R59.1, R60.2, R63.1, R64.2, U14.25 (VCC), U15.6 (VDD), U15.7 (VREGIN), U16.3 (3V3); also elsewhere on the board
/ESP33/CS: U16.20 (IO15); also elsewhere on the board
/ESP33/DTR: U15.15 (~CTS), U16.23 (IO9); also elsewhere on the board
/ESP33/ESP_SIM_PWR: U16.9 (IO4); also elsewhere on the board
/ESP33/ESP_SIM_RST: U16.10 (IO5); also elsewhere on the board
/ESP33/ESP_SIM_RX: U16.6 (IO3); also elsewhere on the board
/ESP33/ESP_SIM_TX: U16.24 (IO18); also elsewhere on the board
/ESP33/IRQ: U16.13 (IO1); also elsewhere on the board
/ESP33/LORA_AUX: R60.1, U14.24 (AUX), U16.27 (IO21)
/ESP33/LORA_MD0: R58.1, U14.20 (M0), U16.28 (IO22)
/ESP33/LORA_MD1: R57.1, U14.21 (M1), U16.29 (IO23)
/ESP33/LORA_RX: U14.22 (RXD), U16.26 (IO20)
/ESP33/LORA_TX: U14.23 (TXD), U16.25 (IO19)
/ESP33/MISO: U16.19 (IO14); also elsewhere on the board
/ESP33/MOSI/SDA: R64.1, U16.18 (IO13); also elsewhere on the board
/ESP33/RES: U16.5 (IO2); also elsewhere on the board
/ESP33/RTS: U15.16 (~RTS), U16.8 (EN); also elsewhere on the board
/ESP33/RX_TX: U15.17 (RXD), U16.31 (TXD0)
/ESP33/SCLK/SCL: R63.2, U16.17 (IO12); also elsewhere on the board
/ESP33/TX_RX: U15.18 (TXD), U16.30 (RXD0)
/ESP33/USB_D+: U13.3 (I/O2), U15.4 (D+)
/ESP33/USB_D-: U13.1 (I/O1), U15.5 (D-)
/USB_DN: U13.6 (I/O1); also elsewhere on the board
/USB_DP: U13.4 (I/O2); also elsewhere on the board
/VBUS: R55.1, U13.5 (VBUS); also elsewhere on the board
ESP_PWRKEY: U16.22 (IO8); also elsewhere on the board
GND: C55.2, C56.1, C57.1, C58.2, C59.2, C60.2, C61.2, J14.1 (GND), J14.2 (GND__1), R56.2, R57.2, R58.2, U13.2 (GND), U14.2 (GND), U14.8 (GND), U14.11 (GND), U14.13 (GND), U14.14 (GND), U14.15 (GND), U14.16 (GND), U14.19 (GND), U14.26 (GND), U15.3 (GND), U15.12 (GND), U15.21 (GND), U16.1 (GND), U16.2 (GND), U16.11 (GND), U16.14 (GND), U16.36 (GND), U16.37 (GND), U16.38 (GND), U16.39 (GND), U16.40 (GND), U16.41 (GND), U16.42 (GND), U16.43 (GND), U16.44 (GND), U16.45 (GND), U16.46 (GND), U16.47 (GND), U16.48 (GND), U16.49 (GND), U16.50 (GND), U16.51 (GND), U16.52 (GND), U16.53 (GND); also elsewhere on the board
unnamed: D9.1 (K), R61.2
unnamed: D10.1 (K), R62.2
unnamed: J14.3 (SIG), U14.12 (ANT)
unnamed: C55.1, R55.2, R56.1, U15.8 (VBUS)
unnamed: R59.2, U15.9 (~RST)
unnamed: R62.1, U15.19 (~RXT/GPIO.3)
unnamed: R61.1, U15.20 (~TXT/GPIO.2)

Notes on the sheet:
LORA MODULE
USB_MODULE

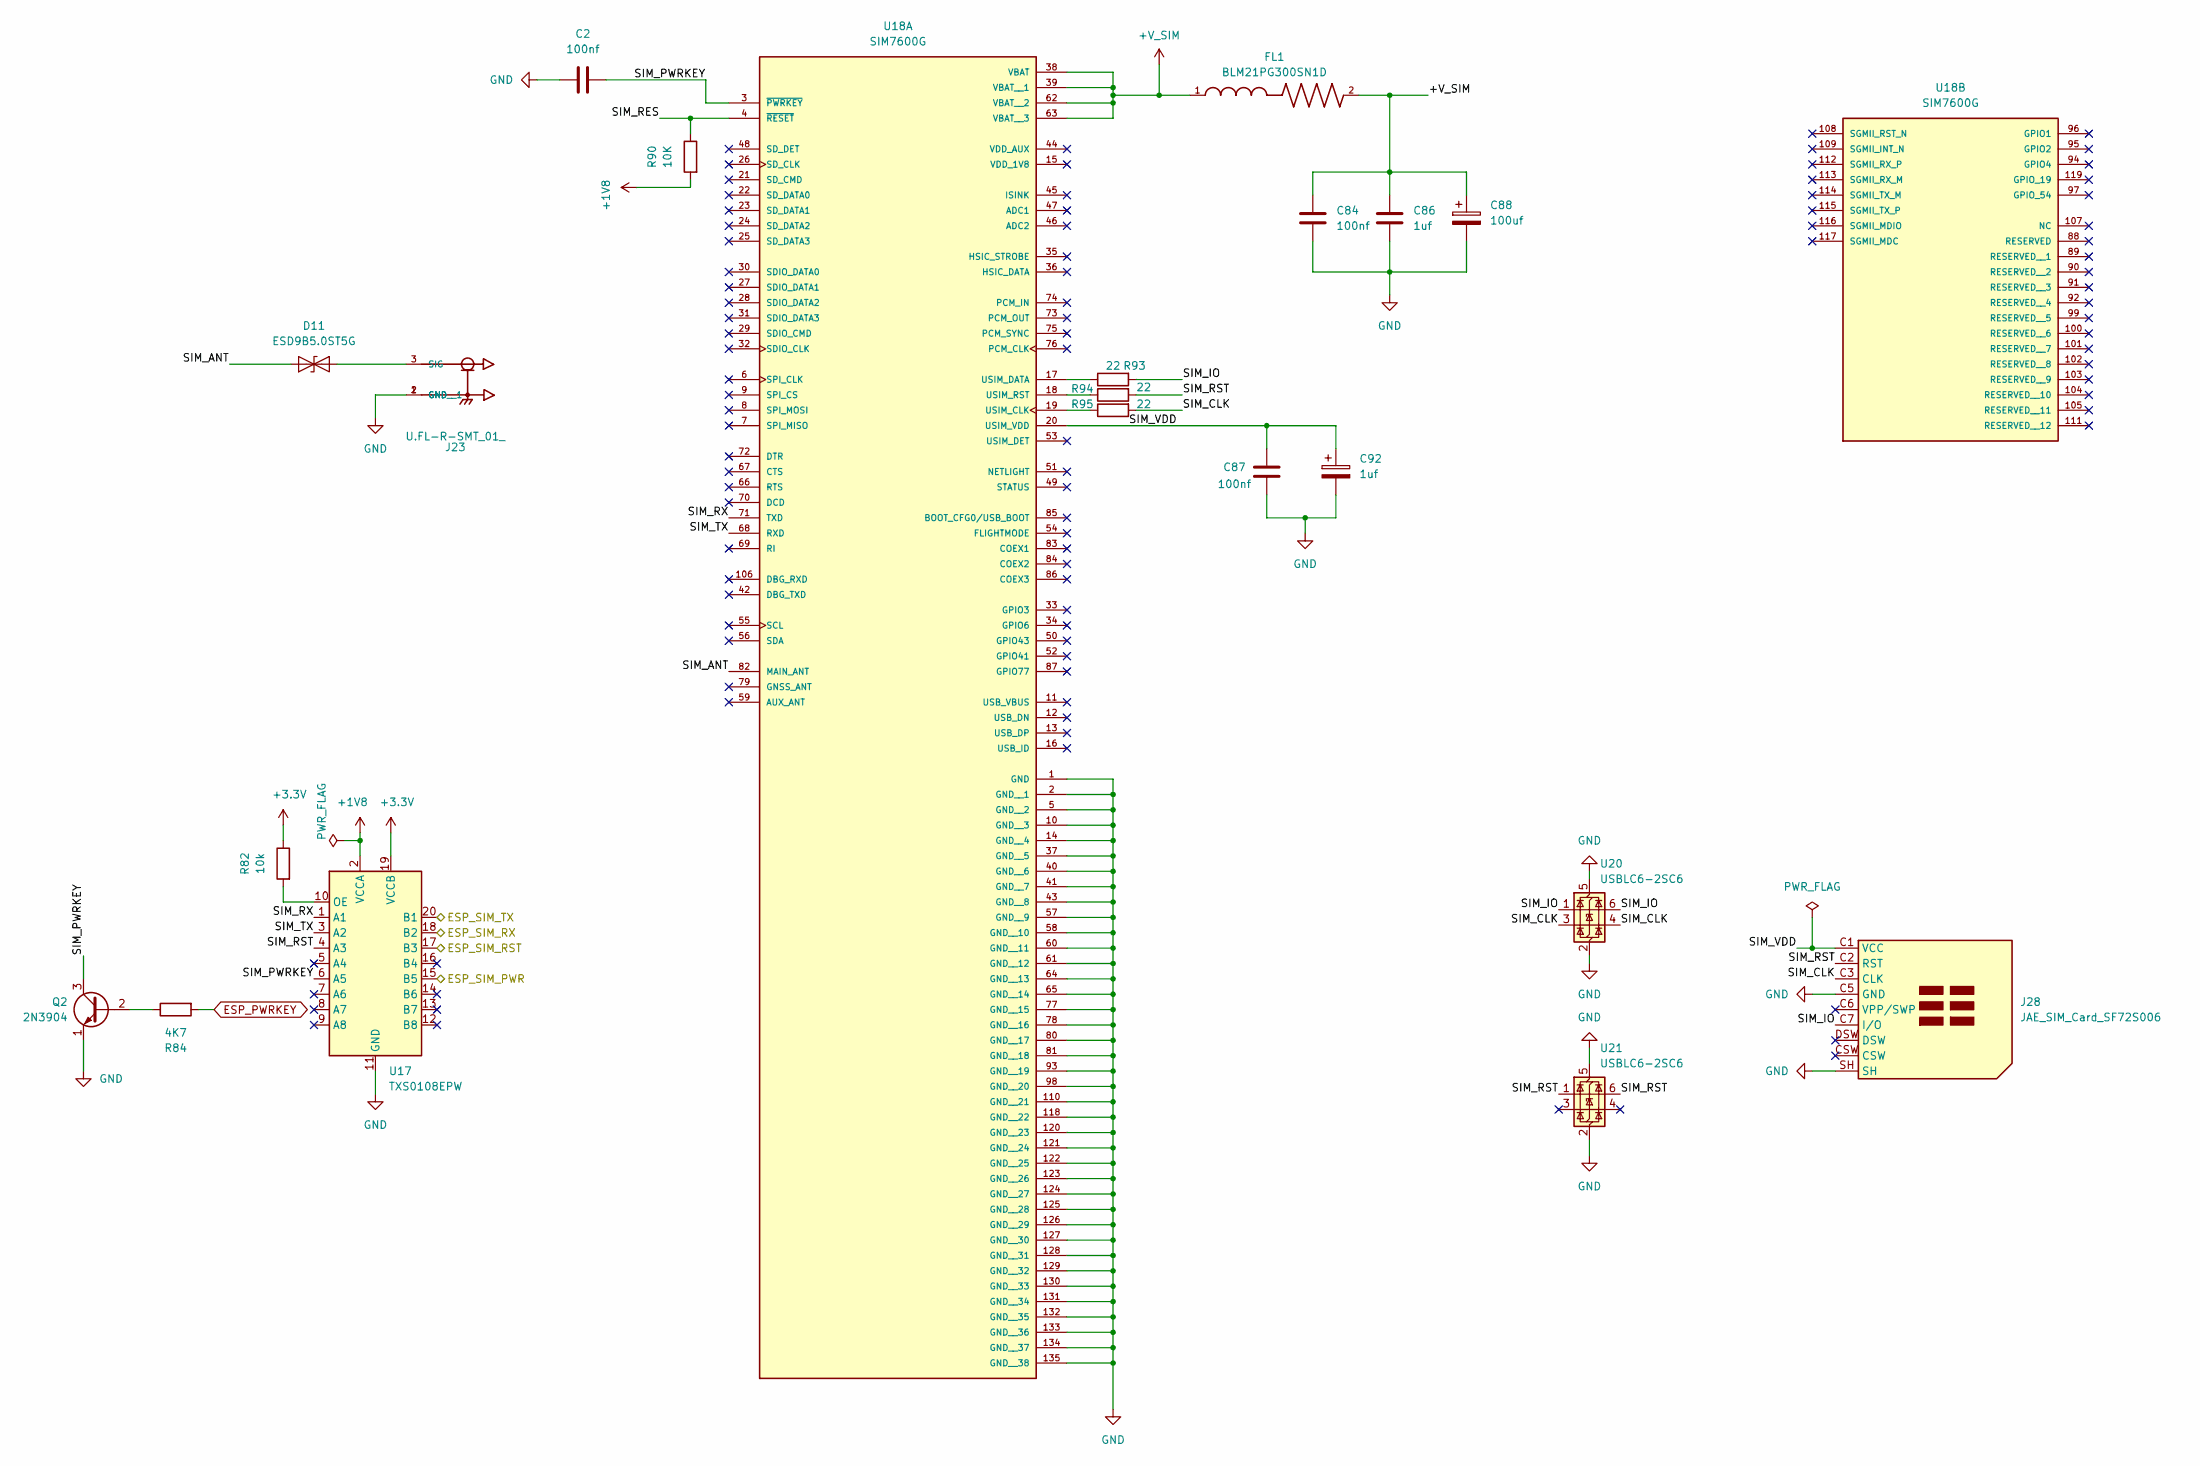
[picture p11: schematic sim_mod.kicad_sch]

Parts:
C2, C84, C87: 100nf; C_0805_2012Metric
C86, C92: 1uf; C_0805_2012Metric
C88: 100uf; C_0805_2012Metric
D11: ESD9B5.0ST5G; D_SOD-923
FL1: BLM21PG300SN1D; BEADC2012X105N
J23: U.FL-R-SMT_01_; HRS_U.FL-R-SMT_01_
J28: JAE_SIM_Card_SF72S006
Q2: 2N3904; TO-92_Inline
R82: 10k; R_0805_2012Metric
R84: 4K7; R_0805_2012Metric
R90: 10K; R_0805_2012Metric
R93, R94, R95: 22; R_0805_2012Metric
U17: TXS0108EPW; TSSOP-20_4.4x6.5mm_P0.65mm
U18: SIM7600G; IC_SIM7600G
U20, U21: USBLC6-2SC6; SOT-23-6

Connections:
+1V8: R90.2, U17.2 (VCCA)
+3.3V: R82.1, U17.19 (VCCB); also elsewhere on the board
+V_SIM: C84.1, C86.1, C88.1, FL1.1, FL1.2, U18.38 (VBAT), U18.39 (VBAT__1), U18.62 (VBAT__2), U18.63 (VBAT__3); also elsewhere on the board
/ESP33/ESP_SIM_PWR: U17.15 (B5); also elsewhere on the board
/ESP33/ESP_SIM_RST: U17.17 (B3); also elsewhere on the board
/ESP33/ESP_SIM_RX: U17.18 (B2); also elsewhere on the board
/ESP33/ESP_SIM_TX: U17.20 (B1); also elsewhere on the board
/ESP33/SIM_MOD/SIM_ANT: D11.1 (A1), U18.82 (MAIN_ANT)
/ESP33/SIM_MOD/SIM_CLK: J28.C3 (CLK), R95.2, U20.3 (I/O2), U20.4 (I/O2)
/ESP33/SIM_MOD/SIM_IO: J28.C7 (I/O), R93.2, U20.1 (I/O1), U20.6 (I/O1)
/ESP33/SIM_MOD/SIM_PWRKEY: C2.2, Q2.3 (C), U17.6 (A5), U18.3 (~PWRKEY)
/ESP33/SIM_MOD/SIM_RES: R90.1, U18.4 (~RESET)
/ESP33/SIM_MOD/SIM_RST: J28.C2 (RST), R94.2, U17.4 (A3), U21.1 (I/O1), U21.6 (I/O1)
/ESP33/SIM_MOD/SIM_RX: U17.1 (A1), U18.71 (TXD)
/ESP33/SIM_MOD/SIM_TX: U17.3 (A2), U18.68 (RXD)
/ESP33/SIM_MOD/SIM_VDD: C87.1, C92.1, J28.C1 (VCC), U18.20 (USIM_VDD)
ESP_PWRKEY: R84.2; also elsewhere on the board
GND: C2.1, C84.2, C86.2, C87.2, C88.2, C92.2, J23.1 (GND), J23.2 (GND__1), J28.C5 (GND), J28.SH, Q2.1 (E), U17.11 (GND), U18.1 (GND), U18.2 (GND__1), U18.5 (GND__2), U18.10 (GND__3), U18.14 (GND__4), U18.37 (GND__5), U18.40 (GND__6), U18.41 (GND__7), U18.43 (GND__8), U18.57 (GND__9), U18.58 (GND__10), U18.60 (GND__11), U18.61 (GND__12), U18.64 (GND__13), U18.65 (GND__14), U18.77 (GND__15), U18.78 (GND__16), U18.80 (GND__17), U18.81 (GND__18), U18.93 (GND__19), U18.98 (GND__20), U18.110 (GND__21), U18.118 (GND__22), U18.120 (GND__23), U18.121 (GND__24), U18.122 (GND__25), U18.123 (GND__26), U18.124 (GND__27), U18.125 (GND__28), U18.126 (GND__29), U18.127 (GND__30), U18.128 (GND__31), U18.129 (GND__32), U18.130 (GND__33), U18.131 (GND__34), U18.132 (GND__35), U18.133 (GND__36), U18.134 (GND__37), U18.135 (GND__38), U20.2 (GND), U20.5 (VBUS), U21.2 (GND), U21.5 (VBUS); also elsewhere on the board
unnamed: D11.2 (A2), J23.3 (SIG)
unnamed: Q2.2 (B), R84.1
unnamed: R82.2, U17.10 (OE)
unnamed: R95.1, U18.19 (USIM_CLK)
unnamed: R93.1, U18.17 (USIM_DATA)
unnamed: R94.1, U18.18 (USIM_RST)

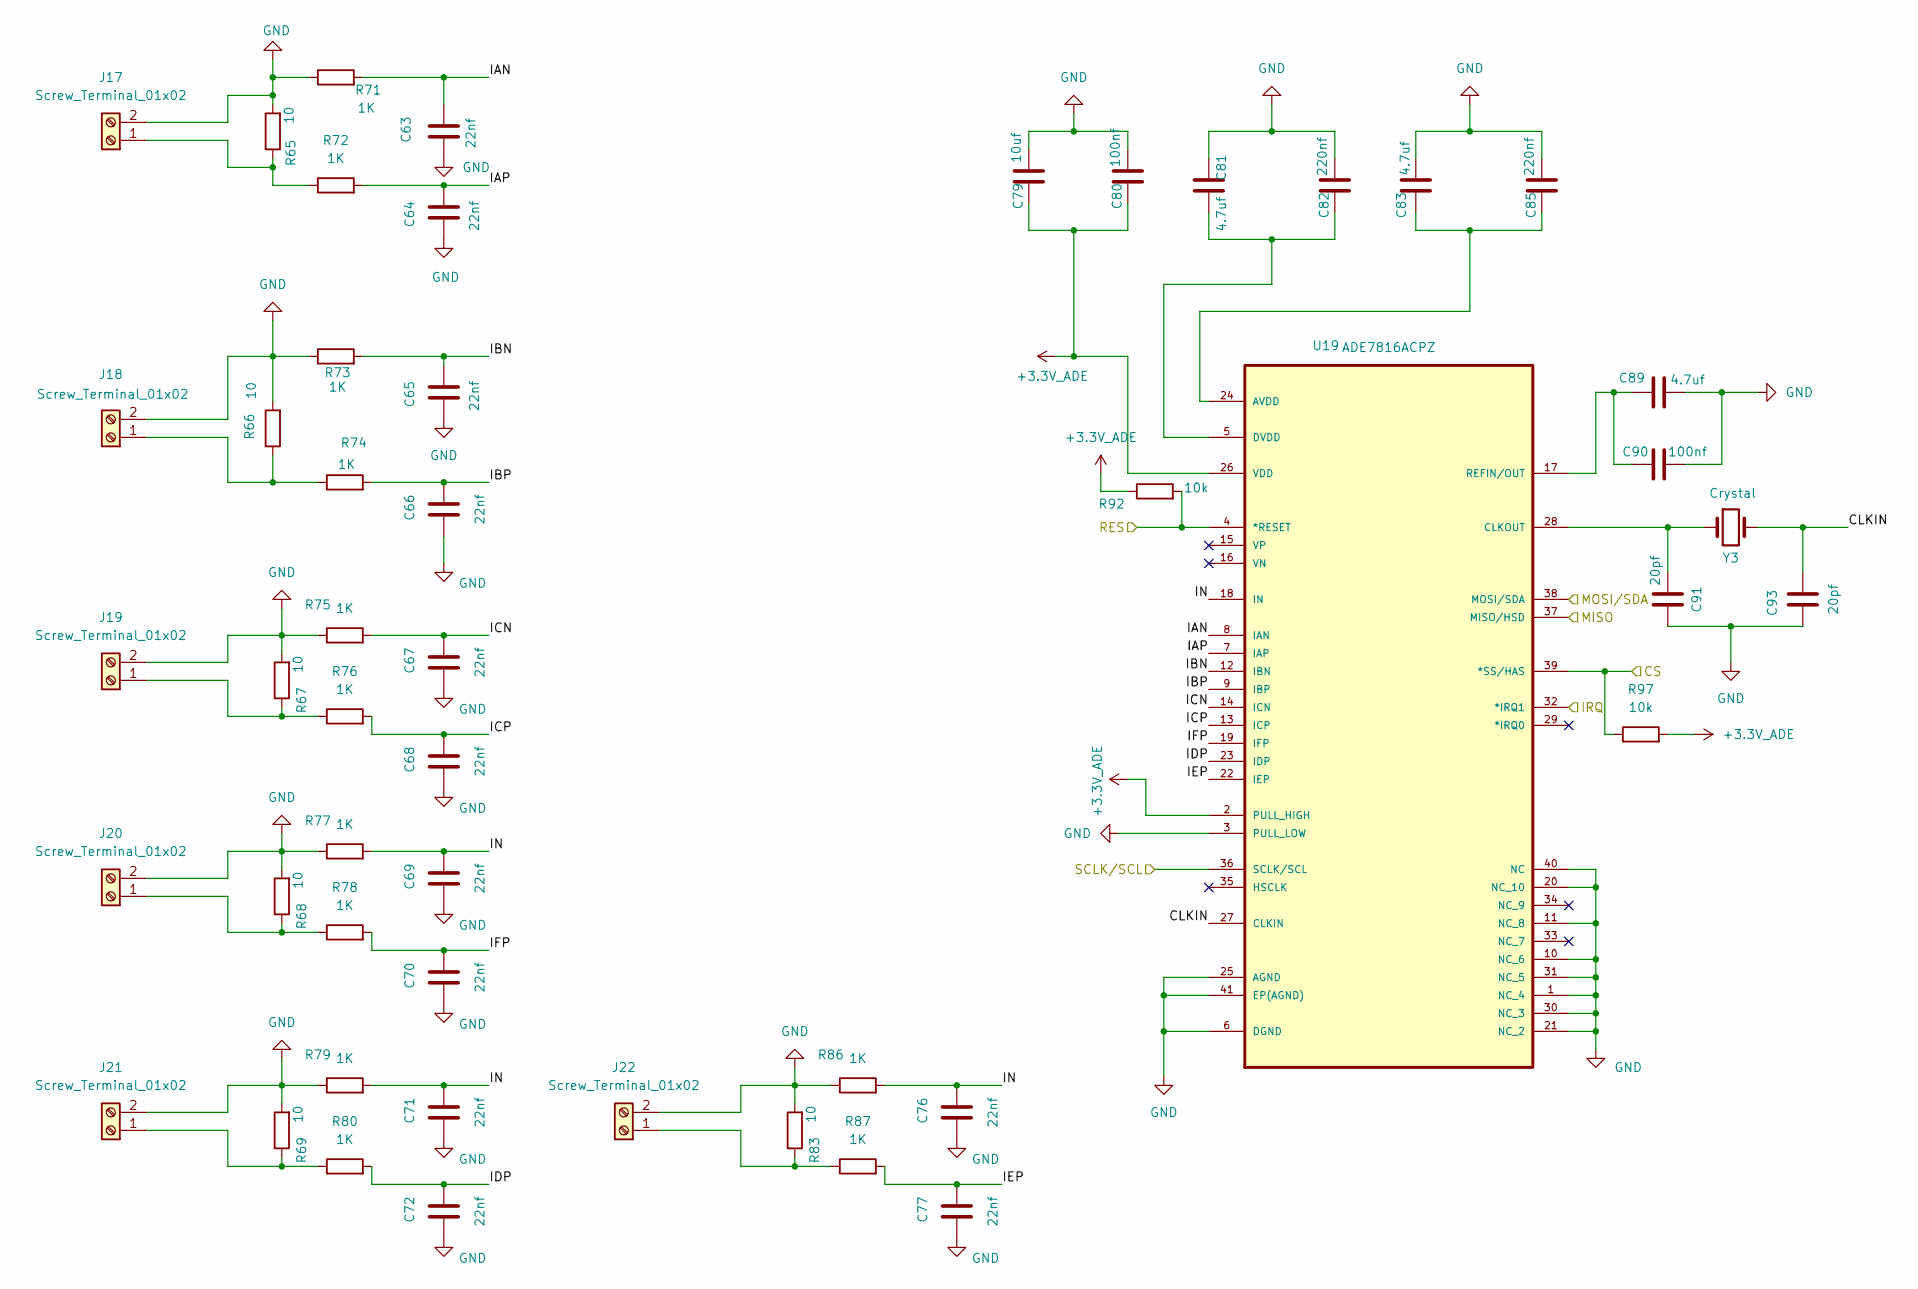
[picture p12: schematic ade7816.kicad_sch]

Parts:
C63, C64, C65, C66, C67, C68, C69, C70, C71, C72, C76, C77: 22nf; C_0805_2012Metric
C79: 10uf; C_0805_2012Metric
C80, C90: 100nf; C_0805_2012Metric
C81, C83, C89: 4.7uf; C_0805_2012Metric
C82, C85: 220nf; C_0805_2012Metric
C91, C93: 20pf; C_0805_2012Metric
J17, J18, J19, J20, J21, J22: Screw_Terminal_01x02; TerminalBlock_Phoenix_MKDS-1,5-2-5.08_1x02_P5.08mm_Horizont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
R65, R66, R67, R68, R69, R83: 10; R_0805_2012Metric
R71, R72, R73, R74, R75, R76, R77, R78, R79, R80, R86, R87: 1K; R_0805_2012Metric
R92, R97: 10k; R_0805_2012Metric
U19: ADE7816ACPZ; QFN50P600X600X80-41N; MPN ADE7816ACPZ
Y3: Crystal; Crystal_SMD_3225-4Pin_3.2x2.5mm

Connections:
+3.3V_ADE: C79.1, C80.1, R92.1, R97.2, U19.2 (PULL_HIGH), U19.26 (VDD); also elsewhere on the board
/ESP33/ADE7816/CLKIN: C93.2, U19.27 (CLKIN), Y3.2
/ESP33/ADE7816/IAN: C63.2, R71.2, U19.8 (IAN)
/ESP33/ADE7816/IAP: C64.2, R72.2, U19.7 (IAP)
/ESP33/ADE7816/IBN: C65.2, R73.2, U19.12 (IBN)
/ESP33/ADE7816/IBP: C66.2, R74.2, U19.9 (IBP)
/ESP33/ADE7816/ICN: C67.2, R75.2, U19.14 (ICN)
/ESP33/ADE7816/ICP: C68.2, R76.2, U19.13 (ICP)
/ESP33/ADE7816/IDP: C72.2, R80.2, U19.23 (IDP)
/ESP33/ADE7816/IEP: C77.2, R87.2, U19.22 (IEP)
/ESP33/ADE7816/IFP: C70.2, R78.2, U19.19 (IFP)
/ESP33/ADE7816/IN: C69.2, C71.2, C76.2, R77.2, R79.2, R86.2, U19.18 (IN)
/ESP33/CS: R97.1, U19.39 (*SS/HAS); also elsewhere on the board
/ESP33/IRQ: U19.32 (*IRQ1); also elsewhere on the board
/ESP33/MISO: U19.37 (MISO/HSD); also elsewhere on the board
/ESP33/MOSI/SDA: U19.36 (SCLK/SCL); also elsewhere on the board
/ESP33/RES: R92.2, U19.4 (*RESET); also elsewhere on the board
/ESP33/SCLK/SCL: U19.38 (MOSI/SDA); also elsewhere on the board
GND: C63.1, C64.1, C65.1, C66.1, C67.1, C68.1, C69.1, C70.1, C71.1, C72.1, C76.1, C77.1, C79.2, C80.2, C81.1, C82.2, C83.2, C85.2, C89.2, C90.2, C91.1, C93.1, J17.2, J18.2, J19.2, J20.2, J21.2, J22.2, R65.2, R66.2, R67.2, R68.2, R69.2, R71.1, R73.1, R75.1, R77.1, R79.1, R83.2, R86.1, U19.1 (NC_4), U19.3 (PULL_LOW), U19.6 (DGND), U19.10 (NC_6), U19.11 (NC_8), U19.20 (NC_10), U19.21 (NC_2), U19.25 (AGND), U19.30 (NC_3), U19.31 (NC_5), U19.40 (NC), U19.41 (EP(AGND)); also elsewhere on the board
unnamed: J17.1, R65.1, R72.1
unnamed: J18.1, R66.1, R74.1
unnamed: J19.1, R67.1, R76.1
unnamed: J20.1, R68.1, R78.1
unnamed: J21.1, R69.1, R80.1
unnamed: J22.1, R83.1, R87.1
unnamed: C83.1, C85.1, U19.24 (AVDD)
unnamed: C91.2, U19.28 (CLKOUT), Y3.1
unnamed: C81.2, C82.1, U19.5 (DVDD)
unnamed: C89.1, C90.1, U19.17 (REFIN/OUT)

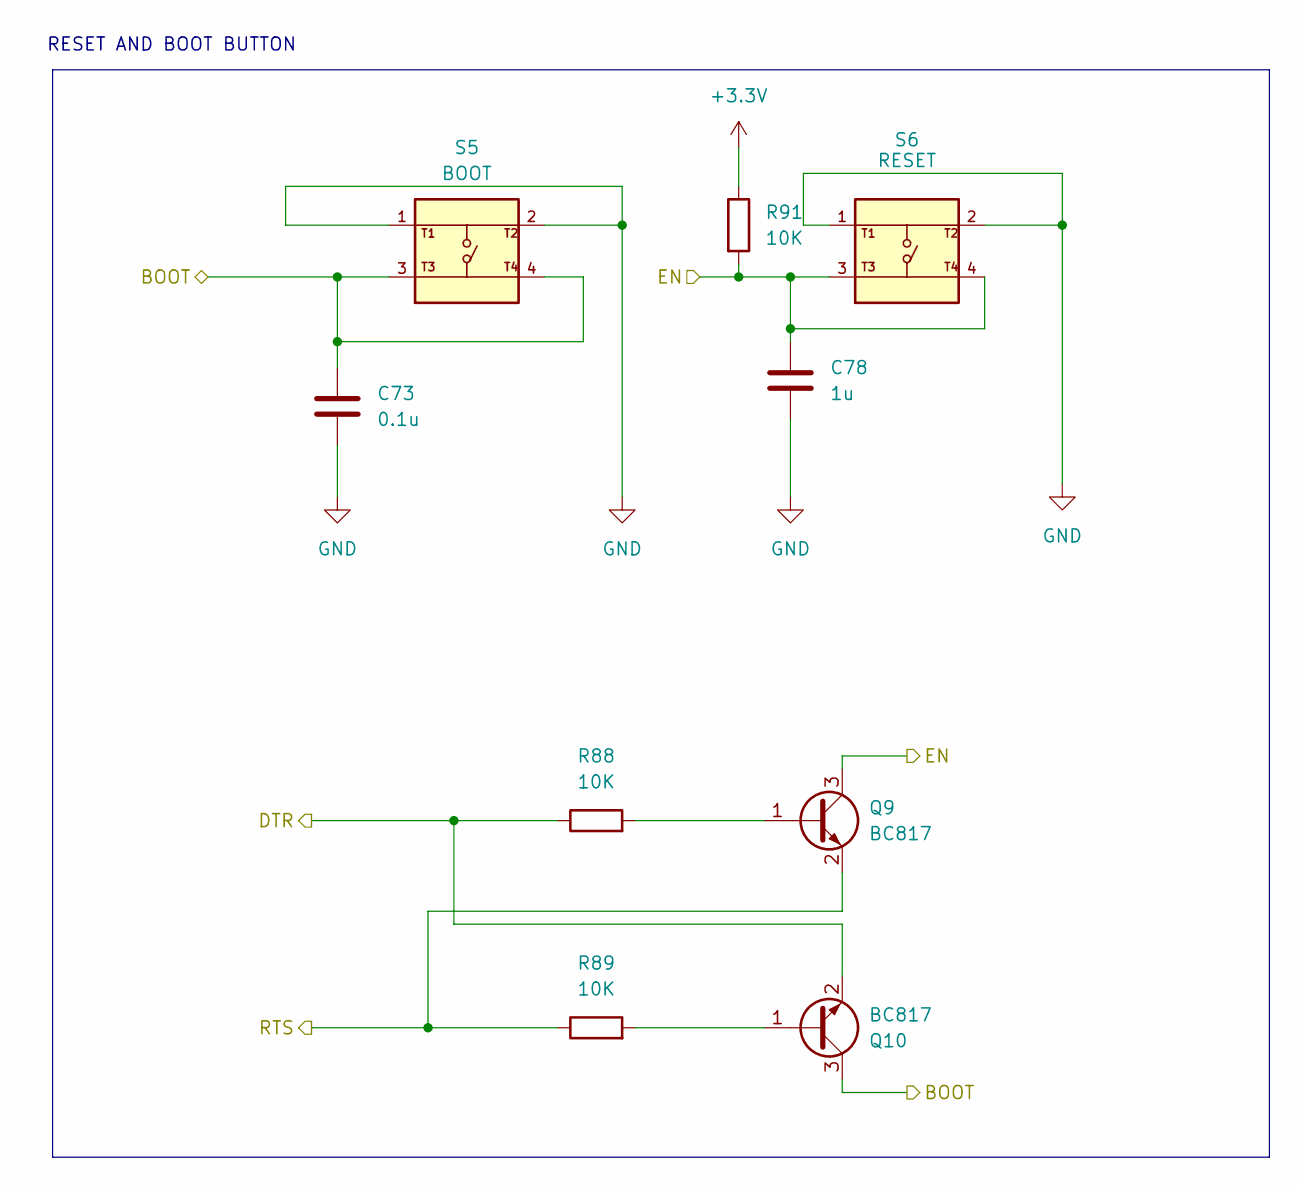
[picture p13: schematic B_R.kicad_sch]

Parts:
C73: 0.1u; C_0805_2012Metric
C78: 1u; C_0805_2012Metric
Q9, Q10: BC817; SOT-23
R88, R89, R91: 10K; R_0805_2012Metric
S5: BOOT; SW_USLPT2819DT2TR; PARTREV P
S6: RESET; SW_USLPT2819DT2TR; PARTREV P

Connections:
+3.3V: R91.1; also elsewhere on the board
/ESP33/BOOT: C73.1, Q10.3 (C), S5.3, S5.4
/ESP33/DTR: Q10.2 (E), R88.1; also elsewhere on the board
/ESP33/EN: C78.1, Q9.3 (C), R91.2, S6.3, S6.4
/ESP33/RTS: Q9.2 (E), R89.1; also elsewhere on the board
GND: C73.2, C78.2, S5.1, S5.2, S6.1, S6.2; also elsewhere on the board
unnamed: Q9.1 (B), R88.2
unnamed: Q10.1 (B), R89.2

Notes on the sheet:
RESET AND BOOT BUTTON

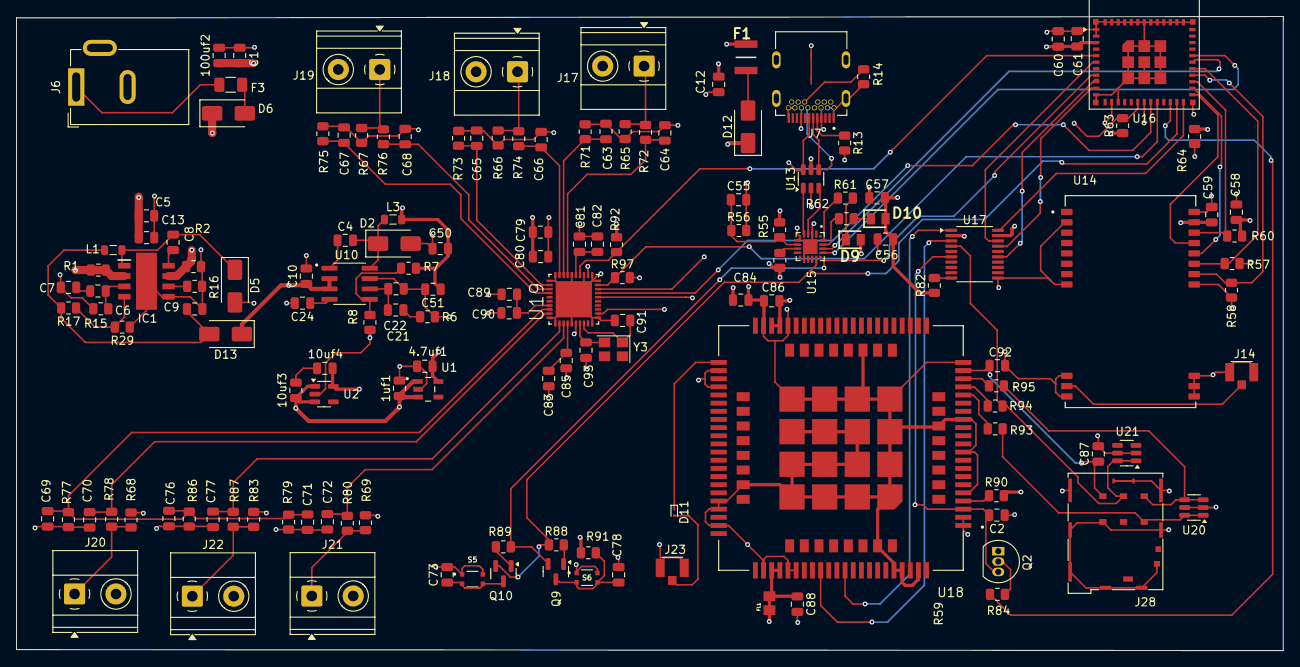
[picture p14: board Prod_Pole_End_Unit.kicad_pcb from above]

Board: 4 copper layers, 155.4 x 77.8 mm, 150 parts (0 on the bottom side), 98 nets.

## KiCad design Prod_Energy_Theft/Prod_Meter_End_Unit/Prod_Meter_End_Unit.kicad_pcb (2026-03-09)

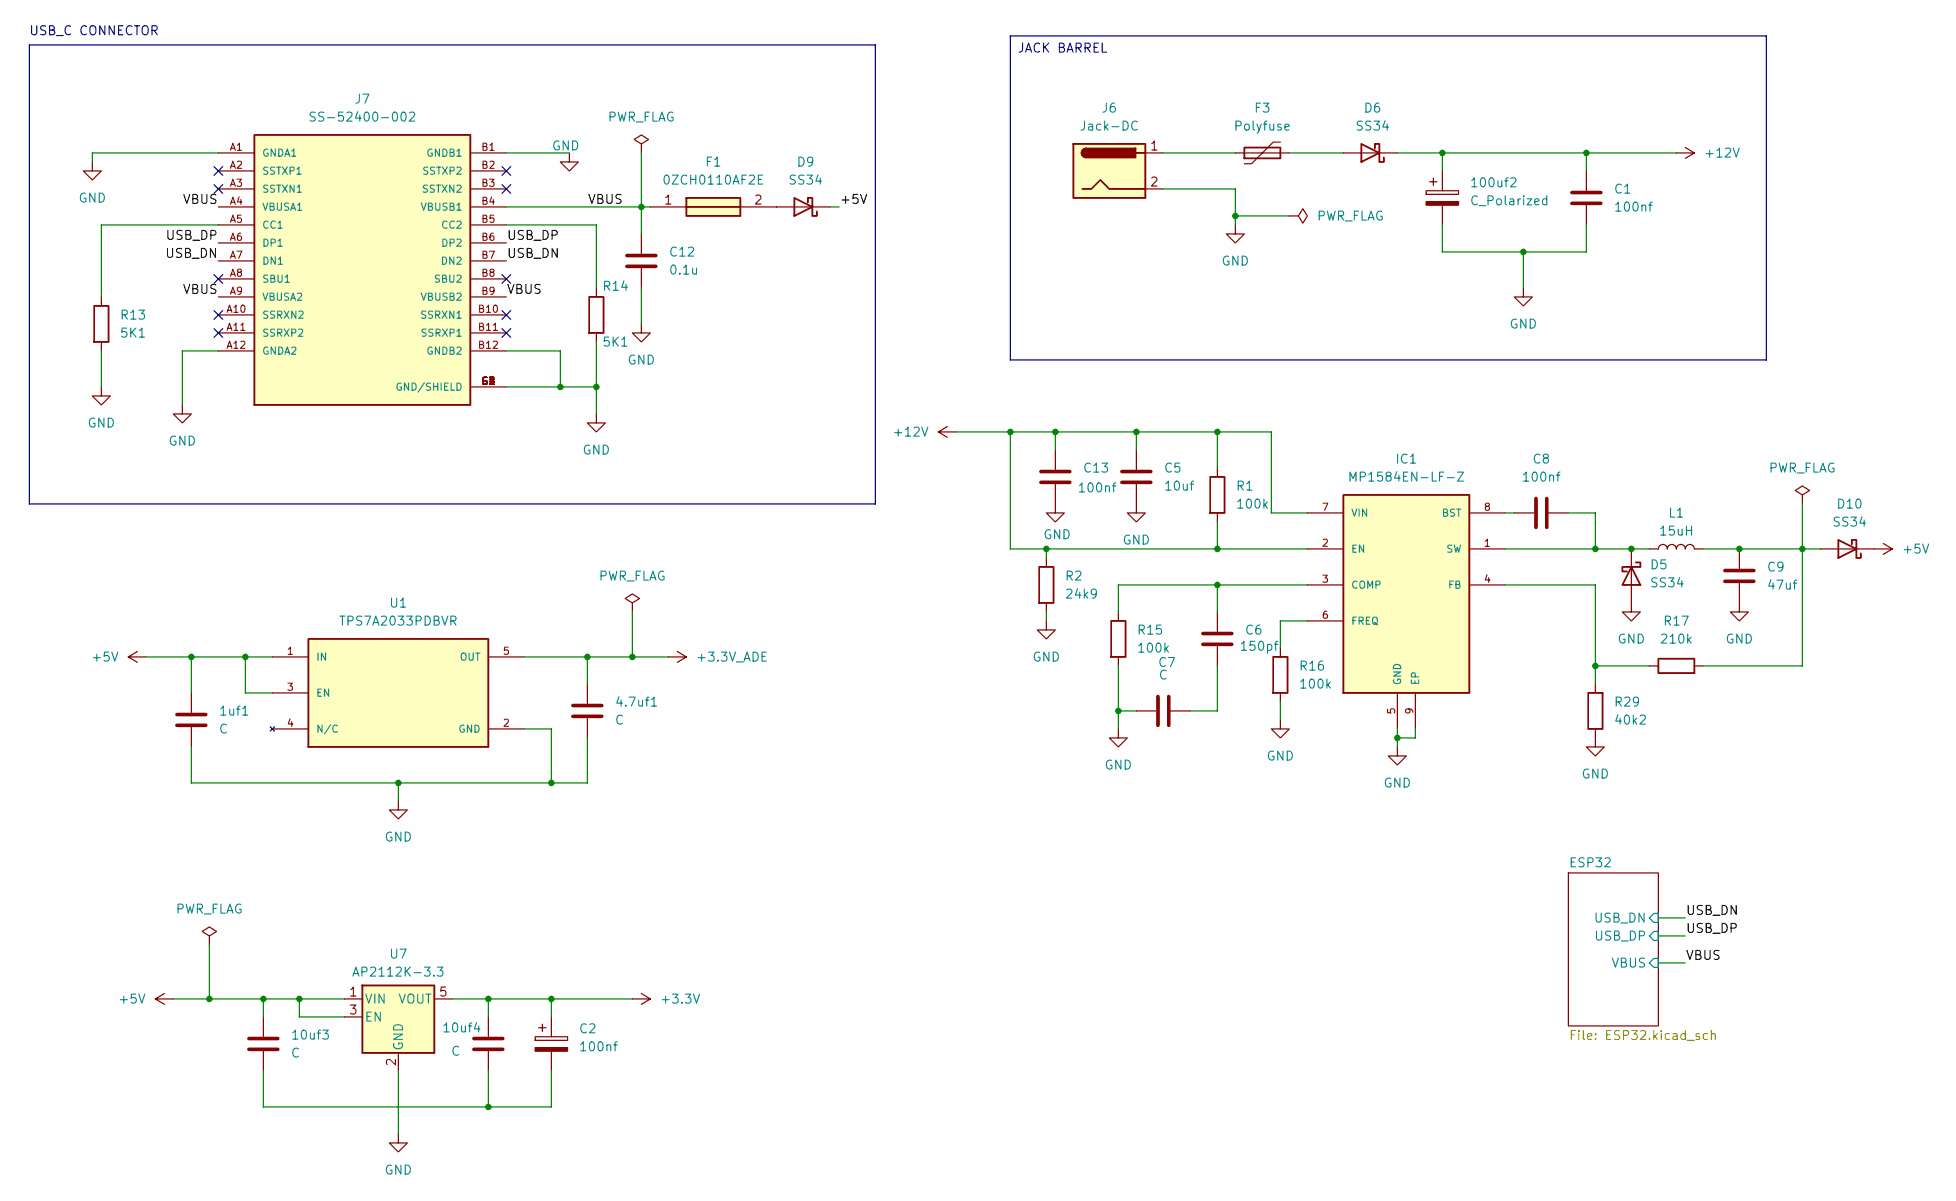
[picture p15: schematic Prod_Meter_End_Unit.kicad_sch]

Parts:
1uf1, 4.7uf1, 10uf3, 10uf4: C; C_0805_2012Metric
100uf2: C_Polarized; C_0805_2012Metric
C1, C2, C8, C13: 100nf; C_0805_2012Metric
C5: 10uf; C_0805_2012Metric
C6: 150pf; C_0805_2012Metric
C7: C; C_0805_2012Metric
C9: 47uf; C_0805_2012Metric; Voltage 16V; MPN GRM32ER71C476KE15
C12: 0.1u; C_0805_2012Metric
D5, D6, D9, D10: SS34; D_SMA
F1: 0ZCH0110AF2E; FUSC3226X100N; Manufacturer_Part_Number 0ZCH0110AF2E
F3: Polyfuse; Fuse_1206_3216Metric
IC1: MP1584EN-LF-Z; SOIC127P600X170-9N; MOUSER_PART_NUMBER 946-MP1584ENLFZ
J6: Jack-DC; BarrelJack_GCT_DCJ200-10-A_Horizontal
J7: SS-52400-002; BELFUSE_SS-52400-002; PARTREV A0
L1: 15uH; L_0805_2012Metric
R1, R15, R16: 100k; R_0805_2012Metric
R2: 24k9; R_0805_2012Metric
R13, R14: 5K1; R_0805_2012Metric
R17: 210k; R_0805_2012Metric
R29: 40k2; R_0805_2012Metric
U1: TPS7A2033PDBVR; SOT95P280X145-5N; PARTREV H
U7: AP2112K-3.3; SOT-23-5

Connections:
+3.3V: 10uf4.1, C2.1, U7.5 (VOUT); also elsewhere on the board
+3.3V_ADE: 4.7uf1.1, U1.5 (OUT); also elsewhere on the board
+5V: 1uf1.1, 10uf3.1, D9.1 (K), D10.1 (K), U1.1 (IN), U1.3 (EN), U7.1 (VIN), U7.3 (EN)
+12V: 100uf2.1, C1.1, C5.1, C13.1, D6.1 (K), IC1.2 (EN), IC1.7 (VIN), R1.1, R1.2, R2.1; also elsewhere on the board
/USB_DN: J7.A7 (DN1), J7.B7 (DN2); also elsewhere on the board
/USB_DP: J7.A6 (DP1), J7.B6 (DP2); also elsewhere on the board
/VBUS: C12.1, F1.1, J7.A4 (VBUSA1), J7.A9 (VBUSA2), J7.B4 (VBUSB1), J7.B9 (VBUSB2); also elsewhere on the board
GND: 1uf1.2, 4.7uf1.2, 100uf2.2, C1.2, C5.2, C7.1, C9.2, C12.2, C13.2, D5.2 (A), IC1.5 (GND), IC1.9 (EP), J6.2, J7.A1 (GNDA1), J7.A12 (GNDA2), J7.B1 (GNDB1), J7.B12 (GNDB2), J7.G1 (GND/SHIELD), J7.G2 (GND/SHIELD), J7.G3 (GND/SHIELD), J7.G4 (GND/SHIELD), J7.S1 (GND/SHIELD), J7.S2 (GND/SHIELD), J7.S3 (GND/SHIELD), J7.S4 (GND/SHIELD), R2.2, R13.2, R14.2, R15.2, R16.2, R29.1, U1.2 (GND), U7.2 (GND); also elsewhere on the board
unnamed: 10uf3.2, 10uf4.2, C2.2
unnamed: C6.2, C7.2
unnamed: C8.2, D5.1 (K), IC1.1 (SW), L1.1
unnamed: D6.2 (A), F3.2
unnamed: D9.2 (A), F1.2
unnamed: C9.1, D10.2 (A), L1.2, R17.2
unnamed: F3.1, J6.1
unnamed: C8.1, IC1.8 (BST)
unnamed: C6.1, IC1.3 (COMP), R15.1
unnamed: IC1.4 (FB), R17.1, R29.2
unnamed: IC1.6 (FREQ), R16.1
unnamed: J7.A5 (CC1), R13.1
unnamed: J7.B5 (CC2), R14.1

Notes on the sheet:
USB_C CONNECTOR
JACK BARREL

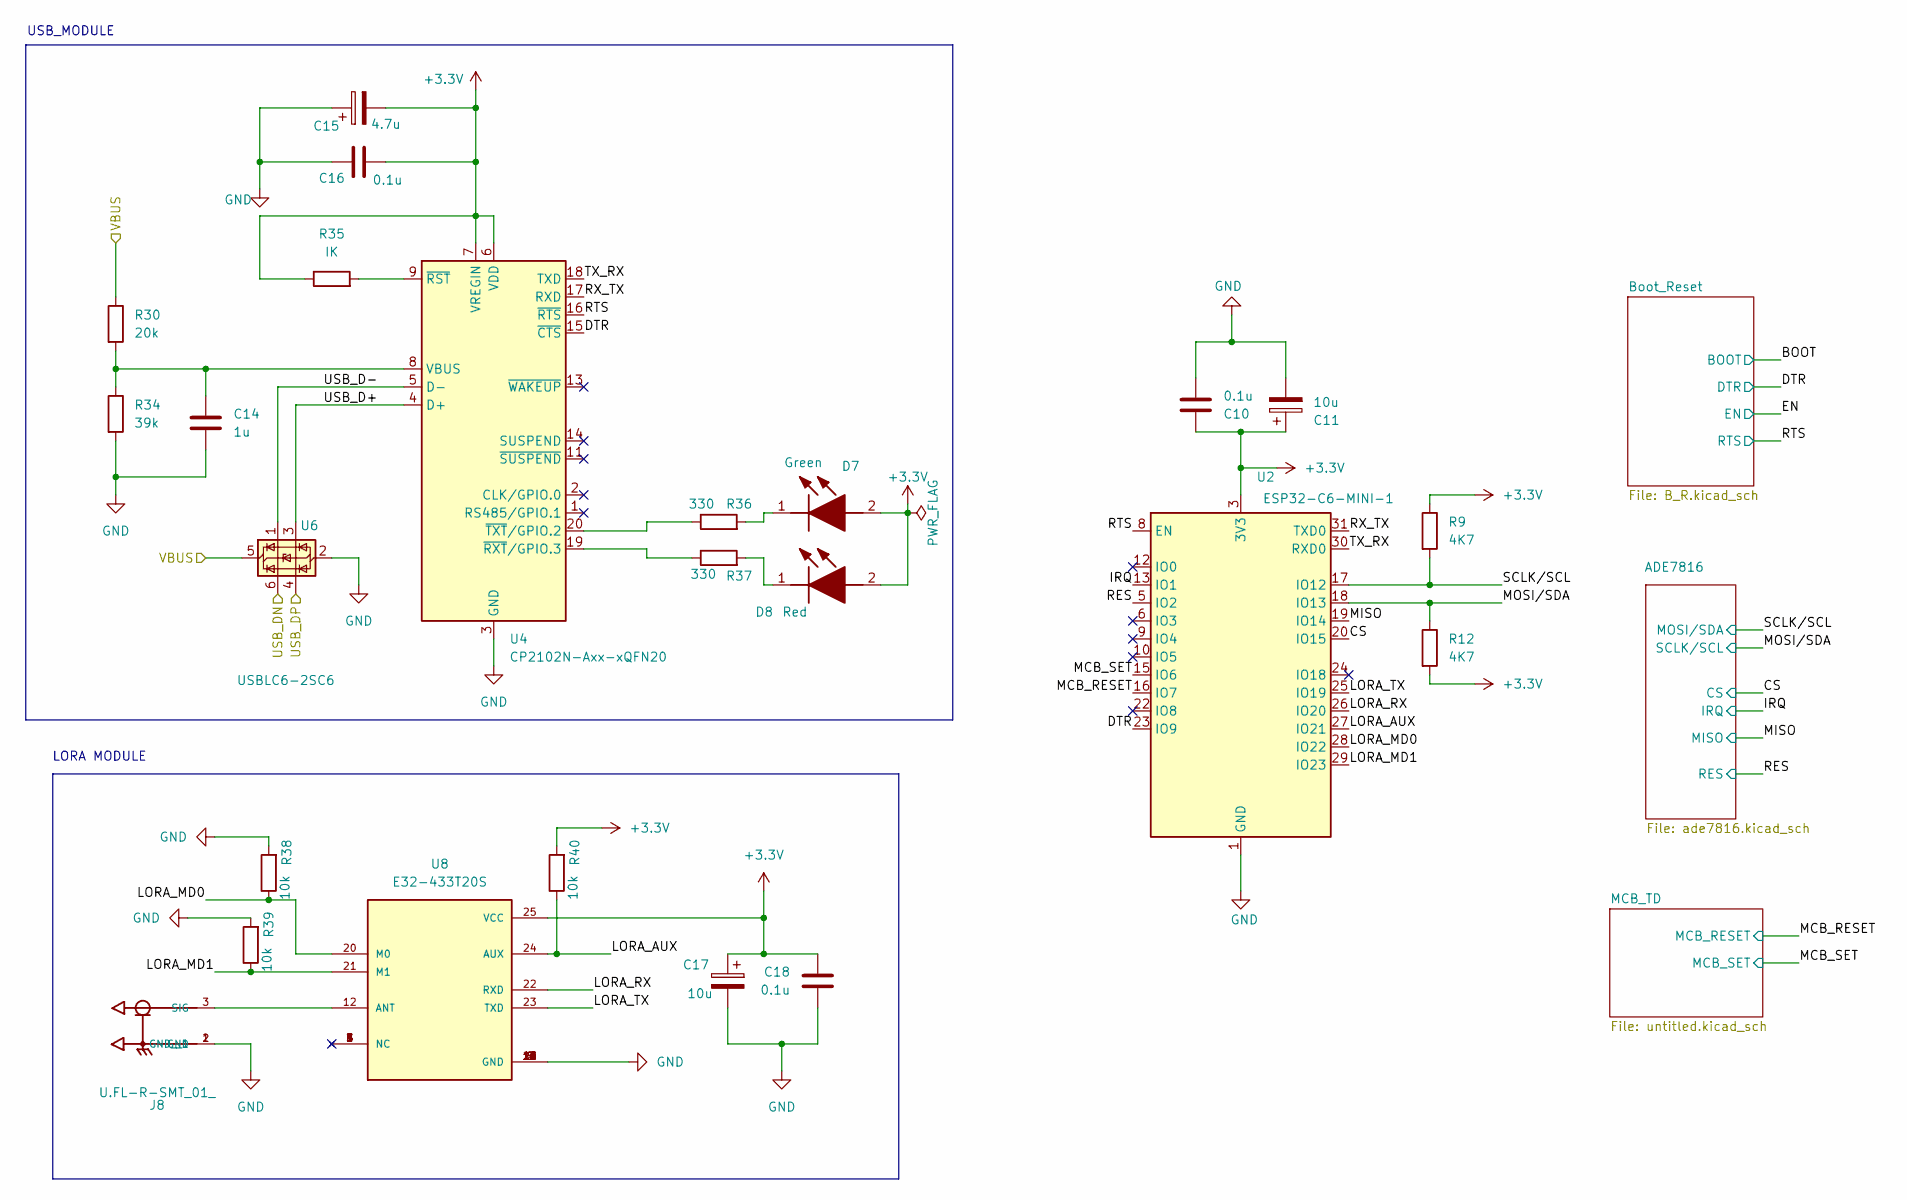
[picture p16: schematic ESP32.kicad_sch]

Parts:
C10, C16, C18: 0.1u; C_0805_2012Metric
C11, C17: 10u; C_0805_2012Metric
C14: 1u; C_0805_2012Metric
C15: 4.7u; C_0805_2012Metric
D7: Green; LEDC2012X120N; Manufacturer_Part_Number LTST-C170GKT; Mouser Part Number 859-LTST-C170GKT
D8: Red; LEDC2012X120N; Manufacturer_Part_Number LTST-C170KRKT; Mouser Part Number 859-LTST-C170KRKT
J8: U.FL-R-SMT_01_; HRS_U.FL-R-SMT_01_
R9, R12: 4K7; R_0805_2012Metric
R30: 20k; R_0805_2012Metric
R34: 39k; R_0805_2012Metric
R35: IK; R_0805_2012Metric
R36, R37: 330; R_0805_2012Metric
R38, R39, R40: 10k; R_0805_2012Metric
U2: ESP32-C6-MINI-1
U4: CP2102N-Axx-xQFN20; IC_CP2102N-A01-GQFN20
U6: USBLC6-2SC6; SOT-23-6
U8: E32-433T20S; MODULE_E32-433T20S; PARTREV 1.00

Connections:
+3.3V: C10.1, C11.1, C15.2, C16.2, C17.1, C18.1, D7.2 (A), D8.2 (A), R9.1, R12.2, R35.1, R40.2, U2.3 (3V3), U4.6 (VDD), U4.7 (VREGIN), U8.25 (VCC); also elsewhere on the board
/ESP32/CS: U2.20 (IO15); also elsewhere on the board
/ESP32/DTR: U2.23 (IO9), U4.15 (~CTS); also elsewhere on the board
/ESP32/IRQ: U2.13 (IO1); also elsewhere on the board
/ESP32/LORA_AUX: R40.1, U2.27 (IO21), U8.24 (AUX)
/ESP32/LORA_MD0: R38.1, U2.28 (IO22), U8.20 (M0)
/ESP32/LORA_MD1: R39.1, U2.29 (IO23), U8.21 (M1)
/ESP32/LORA_RX: U2.26 (IO20), U8.22 (RXD)
/ESP32/LORA_TX: U2.25 (IO19), U8.23 (TXD)
/ESP32/MCB_RESET: U2.16 (IO7); also elsewhere on the board
/ESP32/MCB_SET: U2.15 (IO6); also elsewhere on the board
/ESP32/MISO: U2.19 (IO14); also elsewhere on the board
/ESP32/MOSI/SDA: R12.1, U2.18 (IO13); also elsewhere on the board
/ESP32/RES: U2.5 (IO2); also elsewhere on the board
/ESP32/RTS: U2.8 (EN), U4.16 (~RTS); also elsewhere on the board
/ESP32/RX_TX: U2.31 (TXD0), U4.17 (RXD)
/ESP32/SCLK/SCL: R9.2, U2.17 (IO12); also elsewhere on the board
/ESP32/TX_RX: U2.30 (RXD0), U4.18 (TXD)
/ESP32/USB_D+: U4.4 (D+), U6.3 (I/O2)
/ESP32/USB_D-: U4.5 (D-), U6.1 (I/O1)
/USB_DN: U6.6 (I/O1); also elsewhere on the board
/USB_DP: U6.4 (I/O2); also elsewhere on the board
/VBUS: R30.1, U6.5 (VBUS); also elsewhere on the board
GND: C10.2, C11.2, C14.2, C15.1, C16.1, C17.2, C18.2, J8.1 (GND), J8.2 (GND__1), R34.2, R38.2, R39.2, U2.1 (GND), U2.2 (GND), U2.11 (GND), U2.14 (GND), U2.36 (GND), U2.37 (GND), U2.38 (GND), U2.39 (GND), U2.40 (GND), U2.41 (GND), U2.42 (GND), U2.43 (GND), U2.44 (GND), U2.45 (GND), U2.46 (GND), U2.47 (GND), U2.48 (GND), U2.49 (GND), U2.50 (GND), U2.51 (GND), U2.52 (GND), U2.53 (GND), U4.3 (GND), U4.12 (GND), U4.21 (GND), U6.2 (GND), U8.2 (GND), U8.8 (GND), U8.11 (GND), U8.13 (GND), U8.14 (GND), U8.15 (GND), U8.16 (GND), U8.19 (GND), U8.26 (GND); also elsewhere on the board
unnamed: D7.1 (K), R36.2
unnamed: D8.1 (K), R37.2
unnamed: J8.3 (SIG), U8.12 (ANT)
unnamed: C14.1, R30.2, R34.1, U4.8 (VBUS)
unnamed: R35.2, U4.9 (~RST)
unnamed: R37.1, U4.19 (~RXT/GPIO.3)
unnamed: R36.1, U4.20 (~TXT/GPIO.2)

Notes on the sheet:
LORA MODULE
USB_MODULE

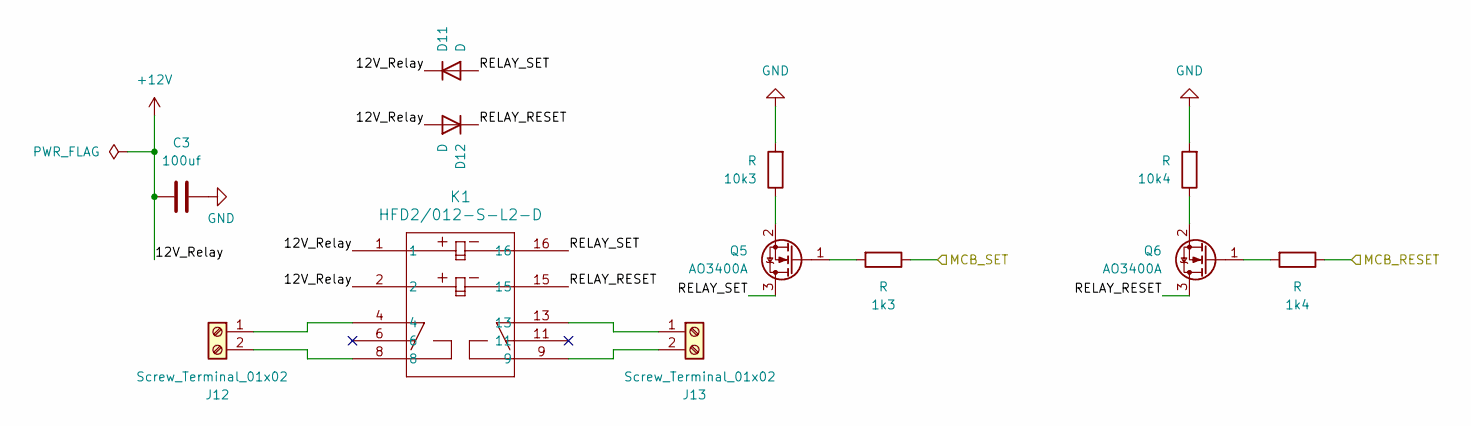
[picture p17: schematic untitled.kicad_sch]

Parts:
1k3, 1k4, 10k3, 10k4: R; R_0805_2012Metric
C3: 100uf; C_0805_2012Metric
D11, D12: D; D_SOD-123
J12, J13: Screw_Terminal_01x02; TerminalBlock_Phoenix_MKDS-1,5-2-5.08_1x02_P5.08mm_Horizont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
K1: HFD2/012-S-L2-D; RELAY10_HFD2&slash_012_HNG
Q5, Q6: AO3400A; SOT-23

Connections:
+12V: C3.1, D11.1 (K), D12.2 (A), K1.1, K1.2; also elsewhere on the board
/ESP32/MCB_RESET: 1k4.1; also elsewhere on the board
/ESP32/MCB_SET: 1k3.1; also elsewhere on the board
/ESP32/MCB_TD/RELAY_RESET: D12.1 (K), K1.15, Q6.3 (D)
/ESP32/MCB_TD/RELAY_SET: D11.2 (A), K1.16, Q5.3 (D)
GND: 10k3.2, 10k4.2, C3.2; also elsewhere on the board
unnamed: J12.1, K1.4
unnamed: J12.2, K1.8
unnamed: J13.1, K1.13
unnamed: J13.2, K1.9
unnamed: 1k3.2, Q5.1 (G)
unnamed: 10k3.1, Q5.2 (S)
unnamed: 1k4.2, Q6.1 (G)
unnamed: 10k4.1, Q6.2 (S)

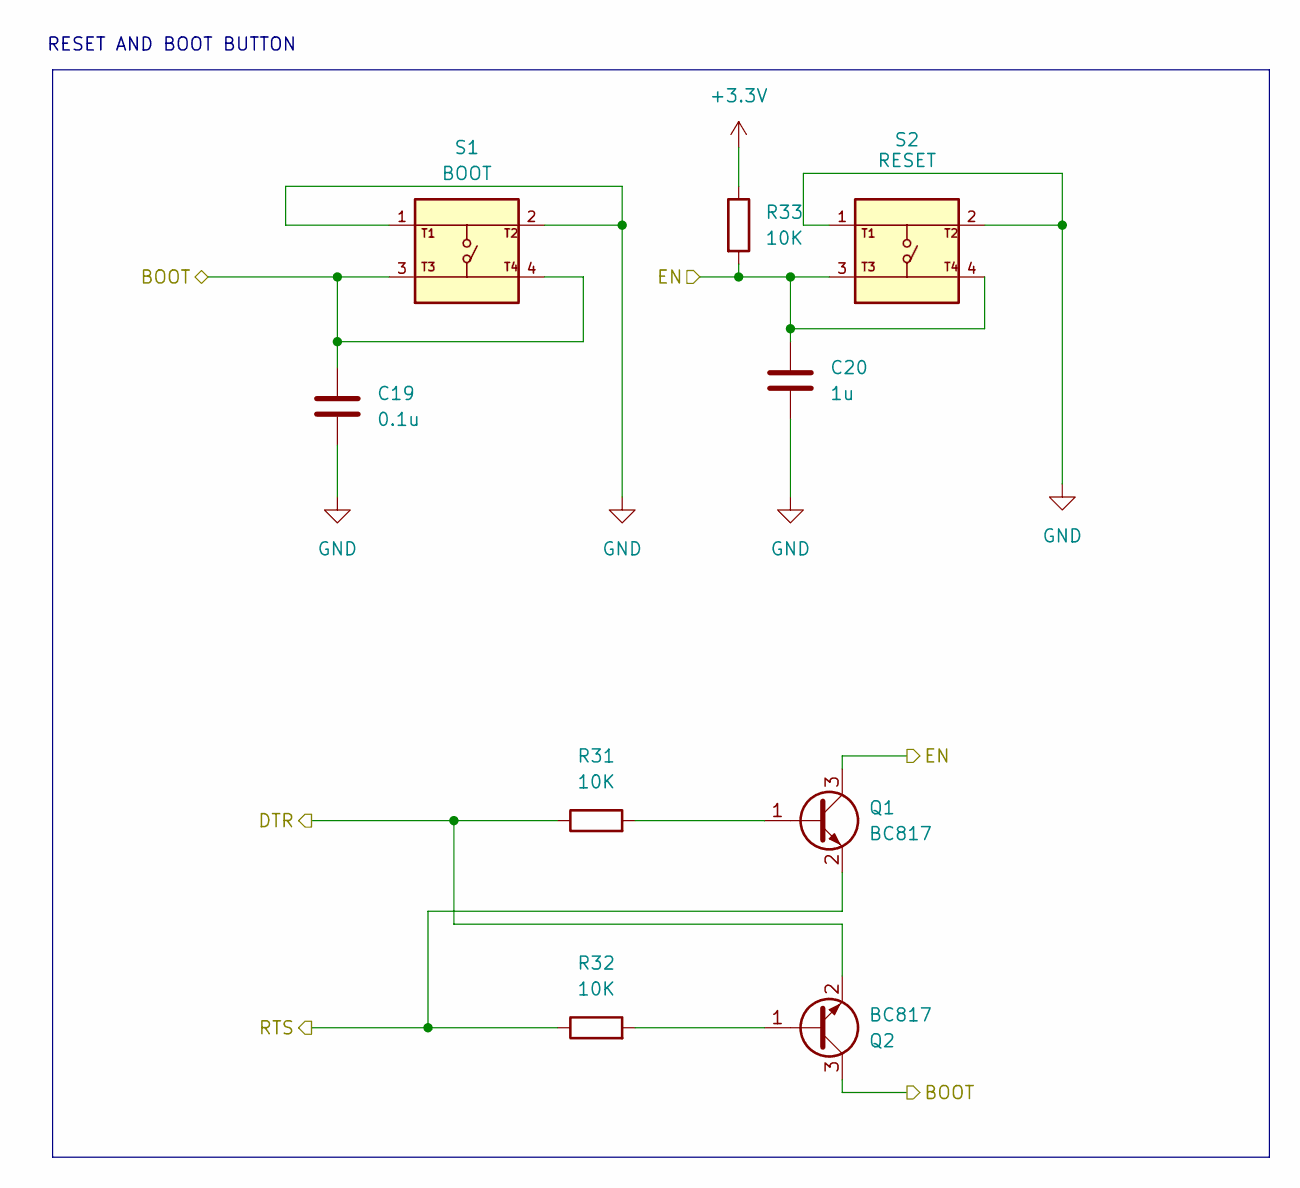
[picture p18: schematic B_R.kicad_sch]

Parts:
C19: 0.1u; C_0805_2012Metric
C20: 1u; C_0805_2012Metric
Q1, Q2: BC817; SOT-23
R31, R32, R33: 10K; R_0805_2012Metric
S1: BOOT; SW_USLPT2819DT2TR; PARTREV P
S2: RESET; SW_USLPT2819DT2TR; PARTREV P

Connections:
+3.3V: R33.1; also elsewhere on the board
/ESP32/BOOT: C19.1, Q2.3 (C), S1.3, S1.4
/ESP32/DTR: Q2.2 (E), R31.1; also elsewhere on the board
/ESP32/EN: C20.1, Q1.3 (C), R33.2, S2.3, S2.4
/ESP32/RTS: Q1.2 (E), R32.1; also elsewhere on the board
GND: C19.2, C20.2, S1.1, S1.2, S2.1, S2.2; also elsewhere on the board
unnamed: Q1.1 (B), R31.2
unnamed: Q2.1 (B), R32.2

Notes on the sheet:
RESET AND BOOT BUTTON

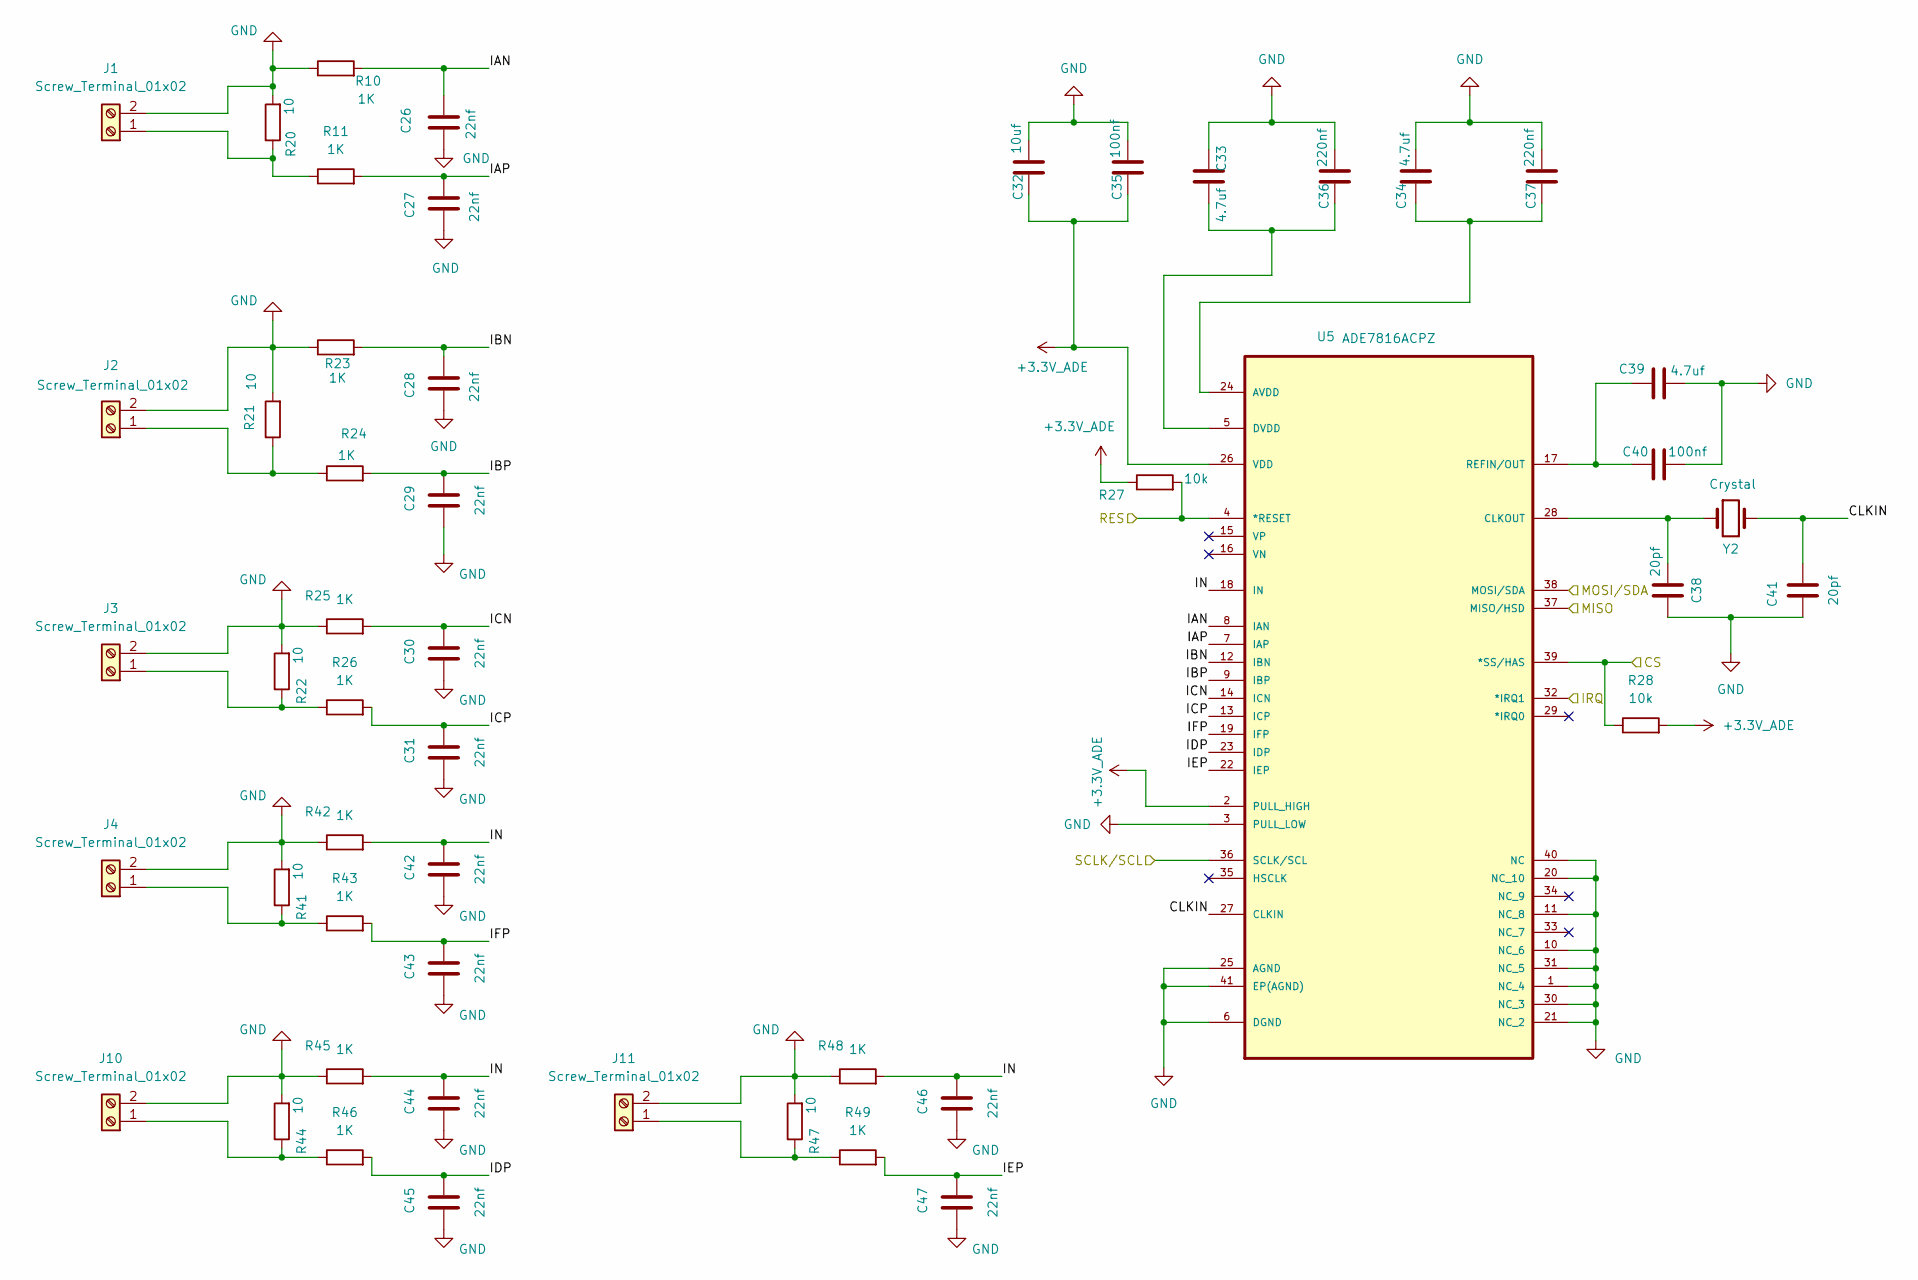
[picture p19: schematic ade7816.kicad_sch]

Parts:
C26, C27, C28, C29, C30, C31, C42, C43, C44, C45, C46, C47: 22nf; C_0805_2012Metric
C32: 10uf; C_0805_2012Metric
C33, C34, C39: 4.7uf; C_0805_2012Metric
C35, C40: 100nf; C_0805_2012Metric
C36, C37: 220nf; C_0805_2012Metric
C38, C41: 20pf; C_0805_2012Metric
J1, J2, J3, J4, J10, J11: Screw_Terminal_01x02; TerminalBlock_Phoenix_MKDS-1,5-2-5.08_1x02_P5.08mm_Horizont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
R10, R11, R23, R24, R25, R26, R42, R43, R45, R46, R48, R49: 1K; R_0805_2012Metric
R20, R21, R22, R41, R44, R47: 10; R_0805_2012Metric
R27, R28: 10k; R_0805_2012Metric
U5: ADE7816ACPZ; QFN50P600X600X80-41N; MPN ADE7816ACPZ
Y2: Crystal; Crystal_SMD_3225-4Pin_3.2x2.5mm

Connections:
+3.3V_ADE: C32.1, C35.1, R27.1, R28.2, U5.2 (PULL_HIGH), U5.26 (VDD); also elsewhere on the board
/ESP32/ADE7816/CLKIN: C41.2, U5.27 (CLKIN), Y2.2
/ESP32/ADE7816/IAN: C26.2, R10.2, U5.8 (IAN)
/ESP32/ADE7816/IAP: C27.2, R11.2, U5.7 (IAP)
/ESP32/ADE7816/IBN: C28.2, R23.2, U5.12 (IBN)
/ESP32/ADE7816/IBP: C29.2, R24.2, U5.9 (IBP)
/ESP32/ADE7816/ICN: C30.2, R25.2, U5.14 (ICN)
/ESP32/ADE7816/ICP: C31.2, R26.2, U5.13 (ICP)
/ESP32/ADE7816/IDP: C45.2, R46.2, U5.23 (IDP)
/ESP32/ADE7816/IEP: C47.2, R49.2, U5.22 (IEP)
/ESP32/ADE7816/IFP: C43.2, R43.2, U5.19 (IFP)
/ESP32/ADE7816/IN: C42.2, C44.2, C46.2, R42.2, R45.2, R48.2, U5.18 (IN)
/ESP32/CS: R28.1, U5.39 (*SS/HAS); also elsewhere on the board
/ESP32/IRQ: U5.32 (*IRQ1); also elsewhere on the board
/ESP32/MISO: U5.37 (MISO/HSD); also elsewhere on the board
/ESP32/MOSI/SDA: U5.36 (SCLK/SCL); also elsewhere on the board
/ESP32/RES: R27.2, U5.4 (*RESET); also elsewhere on the board
/ESP32/SCLK/SCL: U5.38 (MOSI/SDA); also elsewhere on the board
GND: C26.1, C27.1, C28.1, C29.1, C30.1, C31.1, C32.2, C33.1, C34.2, C35.2, C36.2, C37.2, C38.1, C39.2, C40.2, C41.1, C42.1, C43.1, C44.1, C45.1, C46.1, C47.1, J1.2, J2.2, J3.2, J4.2, J10.2, J11.2, R10.1, R20.2, R21.2, R22.2, R23.1, R25.1, R41.2, R42.1, R44.2, R45.1, R47.2, R48.1, U5.1 (NC_4), U5.3 (PULL_LOW), U5.6 (DGND), U5.10 (NC_6), U5.11 (NC_8), U5.20 (NC_10), U5.21 (NC_2), U5.25 (AGND), U5.30 (NC_3), U5.31 (NC_5), U5.40 (NC), U5.41 (EP(AGND)); also elsewhere on the board
unnamed: J1.1, R11.1, R20.1
unnamed: J2.1, R21.1, R24.1
unnamed: J3.1, R22.1, R26.1
unnamed: J4.1, R41.1, R43.1
unnamed: J10.1, R44.1, R46.1
unnamed: J11.1, R47.1, R49.1
unnamed: C34.1, C37.1, U5.24 (AVDD)
unnamed: C38.2, U5.28 (CLKOUT), Y2.1
unnamed: C33.2, C36.1, U5.5 (DVDD)
unnamed: C39.1, C40.1, U5.17 (REFIN/OUT)

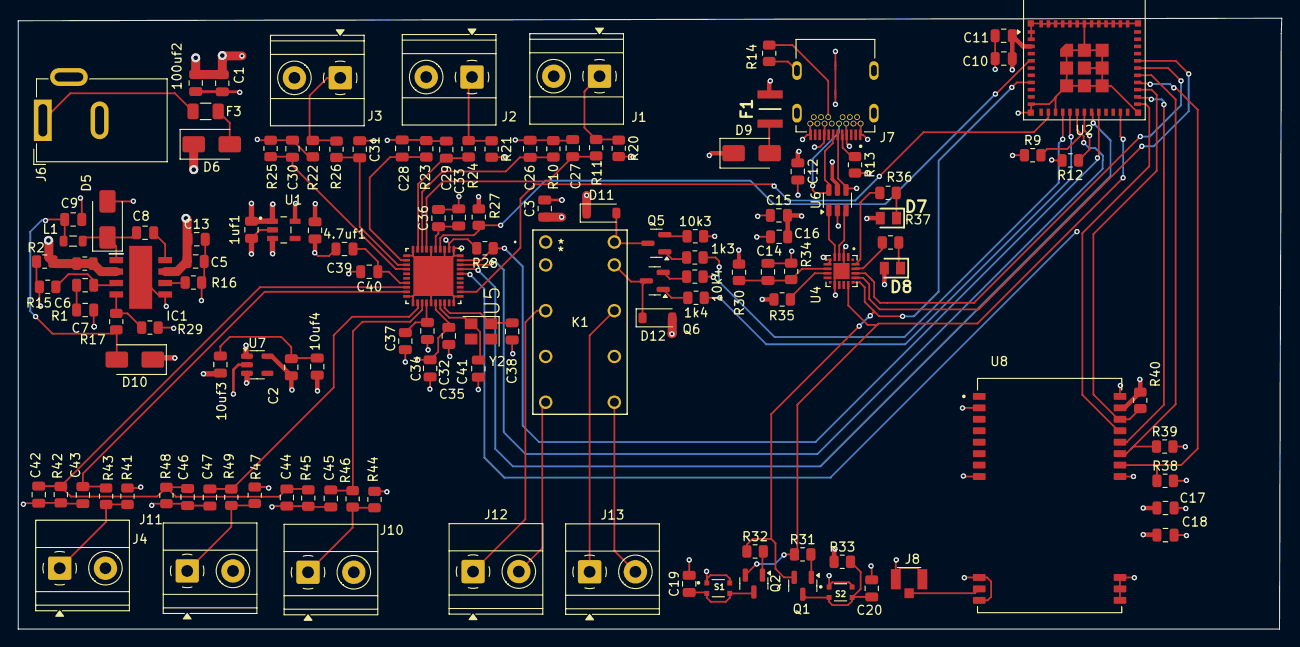
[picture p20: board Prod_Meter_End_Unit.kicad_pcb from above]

Board: 4 copper layers, 140.2 x 67.8 mm, 129 parts (0 on the bottom side), 82 nets.

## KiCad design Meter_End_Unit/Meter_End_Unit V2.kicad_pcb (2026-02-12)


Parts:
C5, C11: 10u; C_0805_2012Metric
C6, C10: 0.1u; C_0805_2012Metric
J4: Conn_01x06_Pin; PinSocket_1x06_P2.54mm_Vertical
R9, R12: 4K7; R_0805_2012Metric
U2: ESP32-C6-MINI-1

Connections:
+3.3V: C5.1, C6.1, C10.1, C11.1, J4.1, R9.1, R12.2, U2.3 (3V3); also elsewhere on the board
/ESP32/CS: U2.20 (IO15); also elsewhere on the board
/ESP32/IRQ: U2.24 (IO18); also elsewhere on the board
/ESP32/LORA_AUX: J4.5, U2.28 (IO22)
/ESP32/LORA_MD0: J4.6, U2.29 (IO23)
/ESP32/LORA_RX: J4.4, U2.27 (IO21)
/ESP32/LORA_TX: J4.3, U2.26 (IO20)
/ESP32/MCB_CTRL: U2.15 (IO6); also elsewhere on the board
/ESP32/MCB_CTRL_D: U2.16 (IO7); also elsewhere on the board
/ESP32/MISO: U2.19 (IO14); also elsewhere on the board
/ESP32/MOSI/SDA: R12.1, U2.18 (IO13); also elsewhere on the board
/ESP32/RES: U2.25 (IO19); also elsewhere on the board
/ESP32/SCLK/SCL: R9.2, U2.17 (IO12); also elsewhere on the board
GND: C5.2, C6.2, C10.2, C11.2, J4.2, U2.1 (GND), U2.2 (GND), U2.11 (GND), U2.14 (GND), U2.36 (GND), U2.37 (GND), U2.38 (GND), U2.39 (GND), U2.40 (GND), U2.41 (GND), U2.42 (GND), U2.43 (GND), U2.44 (GND), U2.45 (GND), U2.46 (GND), U2.47 (GND), U2.48 (GND), U2.49 (GND), U2.50 (GND), U2.51 (GND), U2.52 (GND), U2.53 (GND); also elsewhere on the board


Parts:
10uf3, 10uf4: C; C_0805_2012Metric
100uf2: C_Polarized; C_0805_2012Metric
C1: 100nf; C_0805_2012Metric
D3: D; D_SOD-123
F3: Polyfuse; Fuse_1206_3216Metric
J6: Jack-DC; BarrelJack_GCT_DCJ200-10-A_Horizontal
J17, J18, J19, J20: Screw_Terminal_01x01; TerminalBlock_1x01_P5.08mm
U3: BD00FC0WEFJ; HTSOP-8-1EP_3.9x4.9mm_P1.27mm_EP2.4x3.2mm

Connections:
+3.3V: 10uf4.1, U3.1 (VO), U3.2 (FB); also elsewhere on the board
+5V: 10uf3.1, J19.1, U3.5 (EN), U3.8 (VCC); also elsewhere on the board
+12V: 100uf2.1, C1.1, D3.1 (K), J17.1
GND: 100uf2.2, C1.2, J6.2, J18.1, J20.1, U3.3 (GND), U3.9 (GND); also elsewhere on the board
unnamed: 10uf3.2, 10uf4.2
unnamed: D3.2 (A), F3.2
unnamed: F3.1, J6.1

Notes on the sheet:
POWER_OUTPUT
JACK BARREL
AME117-3.3

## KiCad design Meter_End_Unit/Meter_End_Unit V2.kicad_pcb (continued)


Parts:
C2, C3, C4, C24, C25, C26, C27, C28, C29, C30, C31: 22nf; C_0805_2012Metric
C32: 10uf; C_0805_2012Metric
C33, C34, C39: 4.7uf; C_0805_2012Metric
C35, C40: 100nf; C_0805_2012Metric
C36, C37: 220nf; C_0805_2012Metric
C38, C41: 20pf; C_0805_2012Metric
J1, J2, J3: Screw_Terminal_01x02; TerminalBlock_Phoenix_PTSM-0,5-2-2,5-V-SMD_1x02-1MP_P2.50mm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
J15, J16, J21, J22, J23: Screw_Terminal_01x01; TerminalBlock_1x01_P5.08mm
R3, R5, R7: R; R_0805_2012Metric
R4, R6, R8: 1k; R_0805_2012Metric
R10, R11, R23, R24, R25, R26: 1K; R_0805_2012Metric
R18, R19, R27, R28: 10k; R_0805_2012Metric
R20, R21, R22: 10; R_0805_2012Metric
U5: ADE7816ACPZ; QFN50P600X600X80-41N; MPN ADE7816ACPZ
Y2: Crystal; Crystal_SMD_3225-4Pin_3.2x2.5mm

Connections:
+3.3V: C32.1, C35.1, R27.1, R28.2, U5.2 (PULL_HIGH), U5.26 (VDD); also elsewhere on the board
/ESP32/CS: R28.1, U5.39 (*SS/HAS); also elsewhere on the board
/ESP32/IRQ: U5.32 (*IRQ1); also elsewhere on the board
/ESP32/MISO: U5.37 (MISO/HSD); also elsewhere on the board
/ESP32/MOSI/SDA: U5.36 (SCLK/SCL); also elsewhere on the board
/ESP32/RES: R27.2, U5.4 (*RESET); also elsewhere on the board
/ESP32/SCLK/SCL: U5.38 (MOSI/SDA); also elsewhere on the board
GND: C2.2, C3.2, C4.2, C24.1, C25.1, C26.1, C27.1, C28.1, C29.1, C30.1, C31.1, C32.2, C33.1, C34.2, C35.2, C36.2, C37.2, C38.1, C39.2, C40.2, C41.1, R3.1, R5.1, R7.1, U5.1 (NC_4), U5.3 (PULL_LOW), U5.6 (DGND), U5.10 (NC_6), U5.11 (NC_8), U5.18 (IN), U5.20 (NC_10), U5.21 (NC_2), U5.25 (AGND), U5.30 (NC_3), U5.31 (NC_5), U5.40 (NC), U5.41 (EP(AGND)); also elsewhere on the board
unnamed: J1.1, R11.1, R20.1
unnamed: J1.2, R10.1, R20.2
unnamed: J2.1, R21.1, R24.1
unnamed: J2.2, R21.2, R23.1
unnamed: J3.1, R22.1, R26.1
unnamed: J3.2, R22.2, R25.1
unnamed: J15.1, R18.1
unnamed: J16.1, R19.1
unnamed: J21.1, R3.2, R4.1
unnamed: J22.1, R5.2, R6.1
unnamed: J23.1, R7.2, R8.1
unnamed: C34.1, C37.1, U5.24 (AVDD)
unnamed: C41.2, U5.27 (CLKIN), Y2.2
unnamed: C38.2, U5.28 (CLKOUT), Y2.1
unnamed: C33.2, C36.1, U5.5 (DVDD)
unnamed: C26.2, R10.2, U5.8 (IAN)
unnamed: C27.2, R11.2, U5.7 (IAP)
unnamed: C28.2, R23.2, U5.12 (IBN)
unnamed: C29.2, R24.2, U5.9 (IBP)
unnamed: C30.2, R25.2, U5.14 (ICN)
unnamed: C31.2, R26.2, U5.13 (ICP)
unnamed: C3.1, R6.2, U5.23 (IDP)
unnamed: C4.1, R8.2, U5.22 (IEP)
unnamed: C2.1, R4.2, U5.19 (IFP)
unnamed: C39.1, C40.1, U5.17 (REFIN/OUT)
unnamed: C25.2, R19.2, U5.16 (VN)
unnamed: C24.2, R18.2, U5.15 (VP)


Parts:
1k1, 1k2, 10k1, 10k2: R; R_0805_2012Metric
D2, D4: D; D_SOD-123
J5: Screw_Terminal_01x02; TerminalBlock_Phoenix_PTSM-0,5-2-2,5-V-SMD_1x02-1MP_P2.50mm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
K1: TQ2-L2-5V; RELAY_TQ2_2C_PAN
Q3, Q4: AO3400A; SOT-23

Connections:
+5V: D2.1 (K), D4.2 (A); also elsewhere on the board
/ESP32/MCB_CTRL: 1k1.1; also elsewhere on the board
/ESP32/MCB_CTRL_D: 1k2.1; also elsewhere on the board
GND: 10k1.2, 10k2.2; also elsewhere on the board
unnamed: D2.2 (A), K1.1
unnamed: D4.1 (K), K1.10
unnamed: J5.1, K1.3
unnamed: J5.2, K1.4
unnamed: 10k1.1, Q3.3 (D)
unnamed: 1k1.2, Q3.1 (G)
unnamed: K1.5, Q3.2 (S)
unnamed: 10k2.1, Q4.3 (D)
unnamed: 1k2.2, Q4.1 (G)
unnamed: K1.6, Q4.2 (S)


Board: 4 copper layers, 150.7 x 71.9 mm, 80 parts (0 on the bottom side), 56 nets.

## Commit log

2026-02-02 Initial schematic and PCB design
    [ADE7816ACPZ.step, ESP32.kicad_sch, Meter_End_Unit.csv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]
2026-02-02 Change schematic and PCB design
    [ADE7816ACPZ.step]
2026-02-02 Change in the Pole End Unit
    [ESP32.kicad_sch, ade7816.kicad_sch]
2026-02-02 Update in footprint
    [ESP32.kicad_sch, Meter_End_Unit.csv, Meter_End_Unit.kicad_sch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]
2026-02-12 PCB design for meter
    [ESP32.kicad_sch, Meter_End_Unit V2.kicad_pcb, Meter_End_Unit.csv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]
2026-02-20 Production design
    [BR.kicad_sch, B_R.kicad_sch, ESP32.kicad_sch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]
2026-02-27 Chnages in power and ADE7816
    [ESP32.kicad_sch, Prod_Meter_End_Unit.kicad_sch, Prod_Pole_End_Unit.kicad_sch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]
2026-03-09 PCB Design
    [Prod_Meter_End_Unit.kicad_pcb, Prod_Pole_End_Unit.kicad_pcb, Prod_Pole_End_Unit.kicad_sch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]
2026-03-16 BOM List
    [Meter_End_Unit.csv, Prod_Meter_End_Unit.csv, Prod_Pole_End_Unit.csv]
2026-03-16 Updated BOM List
    [Prod_Meter_End_Unit.csv, Prod_Pole_End_Unit.csv]
2026-03-17 update in BOM list
    [B_R.kicad_sch, ESP32.kicad_sch, Prod_Meter_End_Unit.csv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]
